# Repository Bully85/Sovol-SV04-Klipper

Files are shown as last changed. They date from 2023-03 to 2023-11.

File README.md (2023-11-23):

Pleas use the newest release for download "[Release](https://github.com/Bully85/Sovol-SV04-Klipper/releases)"

# Sovol-SV04-Klipper
This repository contains all the necessary configuration files for the SV04 to work with Klipper's Mirror and Copy modes, including images and descriptions.

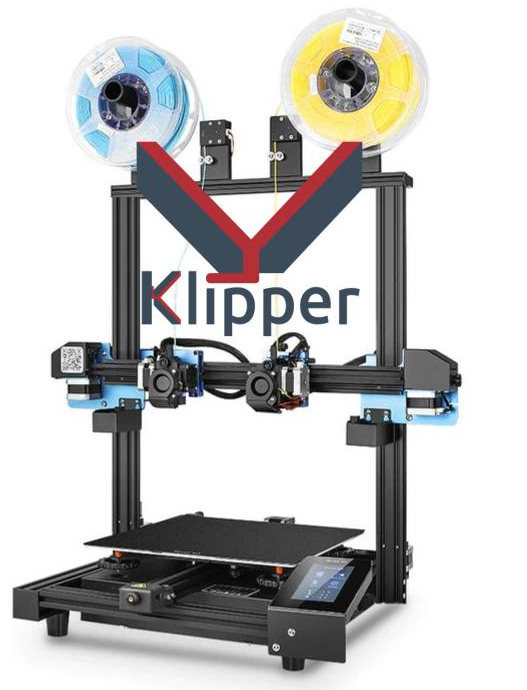
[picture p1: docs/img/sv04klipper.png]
KlipperSV04


# Spenden/Donations

Donate with PayPal (https://www.paypal.com/donate/?hosted_button_id=L85ULXXQKALP6)

# _Für die deutsche Anleitung wählt bitte READMEdeutsch.md_

# new
Click here for the Discord https://discord.gg/22VQXyuq
# update
Attention, the configs have changed with the new update. Please re-insert IDEX_mode.cfg, macros.cfg and Start-End-Macro.cfg. If the display is needed, these are in the config/SV04-with-display folder. Otherwise, if the original klipper is installed, config/SV04-works-with-orign-klipper can also be used but without the orign display

Change the Startcode in the Slicer [Cura](Cura Profile/Startcode.md) [Prusa_Slicer](Prusaslicer Profile/Startcode.md)
# Introduction

Different configs are required for the STM and GD versions of the printer.
Both are included in the "printer.cfg" file and you just need to uncomment the correct one.
You can verify whether your chip is STM or GD by either opening your electric box and checking manually, or there is an error message with the z-Tilt.

This guide will help you set up your SV04 with Klipper, including the COPY and MIRROR modes.

# In Progress

Cura 5.3 is currently not supported, but we are working on it.

# Features

- Copy Mode (supports different temperatures but does not support first layer settings for the right Extruder)
- Mirror Mode (supports different temperatures but does not support first layer settings for the right Extruder)
- Dual Mode
- Single Mode
- Bed Mesh Levelling
- Input Shaping
- Display Functionality
- And much more

# Requirements

- Raspberry Pi 3 or newer with WiFi
    - Pi Zero won't work 
    - Pi 2 may or may not work, not recommended
- Optional but recommended: Original 7" touch screen
- Optional: Camera
- SSH; For example:
    - Powershell and Windows Terminal have SSH built-in
    - alternatively Putty or another SSH program (https://putty.org/)
- SFTP or SCP; For example:
    - FileZilla (https://filezilla-project.org/)
    - WinScp (https://winscp.net)
- Pi Imager (https://www.raspberrypi.com/software/)
- The configuration files provided in this repository
- MicroSD Card for the Raspi (min 8GB, the complete install is ~5.5GB)
- SD Card to flash the SV04 (max 8GB, formatted in Fat32 4096)

# Installation via pre-made OS image

The operating system for the Raspberry Pi can be found in the "[image Raspberry PI 3_4](https://drive.google.com/drive/folders/1rZepxzwUR5QTXRXcv5EBYin_gFiMcKVD)" directory. 
This should be installed onto the MicroSD card using the [Raspberry Pi Imager](https://www.raspberrypi.com/software/). 
Make sure to adjust your WiFi settings before writing the image (you can find them by clicking on the cog wheel in the bottom right corner). 

The firmware.bin file in the "Firmware bin" directory should be placed on the (Full Size)SD card and flashed onto the printer with the original display unplugged (the original display is not needed at this stage as it will not function). 
The files from the "config" directory should now be transferred to the Raspberry Pi as described [below](#transferring-files), or directly in the Mainsail interface, which can be accessed by using the IP address or Hostname.
- the Hostname can be configured in the WiFi Settings in Pi Imager 
- the IP can be found in your router

# Installation on an Existing OS

## Without Kiauh

Coming soon.

## If you use Kiauh
Follow the [Kiauh](https://github.com/th33xitus/kiauh) instructions first, then come back.

- Log in to the Raspberry Pi [via SSH](#using-ssh) and enter the following command:
```sh 
sudo nano kiauh/klipper_repos.txt.example
```

- Add the following line at the end (see image below):
```sh 
https://github.com/Bully85/klipper
```
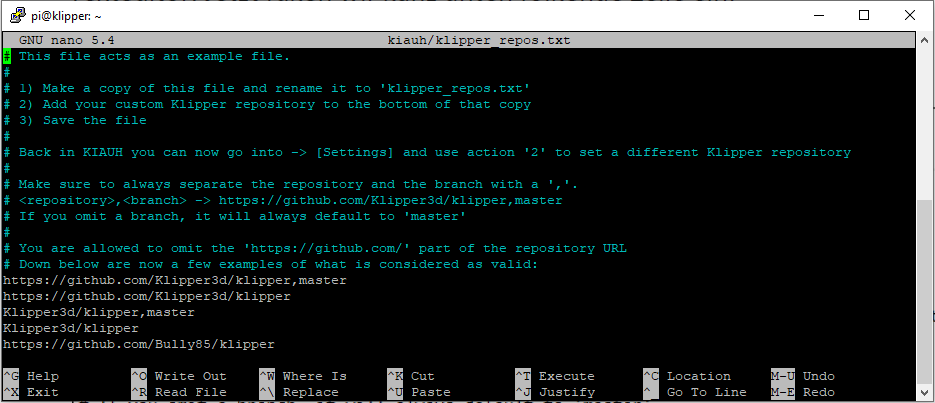
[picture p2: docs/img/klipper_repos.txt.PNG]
KiauhSV04


- Save the file with Ctrl+X -> Y. 
- Rename the file to remove ".example" from the file name and press Enter, then Y. 
- Run Kiauh with the command 
```sh 
./kiauh/kiauh.sh
```
- Select Settings [6] 
- Then [1] to set the custom Klipper repository
- Choose [4] "Bully85/klipper"
- Then confirm everything with [y].

Exit SSH

# Installation on a new OS 

Using the Raspi Imager, install Mainsail OS from 'Other specific-purpose OS' -> '3D printing' -> 'Mainsail OS'.
Then boot your Raspi, connect via SSH, and install [Kiauh](https://github.com/th33xitus/kiauh). 
Now follow the [instructions above](#if-you-use-kiauh) to overwrite the default Klipper install with this one.
Once done connect via SFTP/SCP, and transfer all the files from this repo's 'config' folder into 'printer_data/config/'.
Reboot the Raspi for good measure, and you're done.

# Using SSH

You can use SSH via a graphical interface as mentioned [above](#requirements), or via the Terminal.
If you choose something like putty, follow their instructions.
The Terminal is already installed and usually quicker.
- open the Windows Terminal (it's called Terminal, not the old CMD), or Powershell 
- connect by typing 'ssh username@hostname' and enter your password when prompted
    - username and hostname are the ones you set up [earlier](#installation-via-pre-made-os-image)
    - if you're installing onto an existing OS, I trust that you know the username and hostname/IP
- do what you need...
- to exit, press Ctrl+D

# Transferring Files 

Now, the files and folders from the "config" directory must be copied to your printer's directory on the Raspberry Pi. The default is "printer_data". 
If this is not the case for you, please adjust the paths in the config and .sh files. 

The easiest way to do this is via an SFTP or SCP Program, such as FileZilla or WinScp [mentioned above](#requirements)

# Fixing the Invalid Message in Mainsail

To fix the invalid message in Mainsail, SSH into Klipper and execute the following command:

```sh 
sudo nano ~/printer_data/systemd/moonraker.env
```
moonraker.env1

Append "-g"  to the end of the "MOONRAKER_ARGS" Line: 
moonraker.env2

Quit and save, then reboot. 

In Mainsail, click on 'invalid' and perform a soft repair. Your setup should now be ready!

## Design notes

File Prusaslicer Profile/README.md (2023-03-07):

# Install Profile PrusaSlicer

## Copy and import

- First copy the folder "SV04" in the Folder path:

```sh
C:\Program Files\Prusa3D\PrusaSlicer\resources\profiles
```

- than import the "PrusaSlicer_config_bundle_SV04_Klipper.ini" in PrusaSlicer

## Use

- if you print in dual mode and dont use the other extruder select "NONE" Filament for the not used Extruder

- for the connection with klipper go to printer settings an clic the cog wheel.

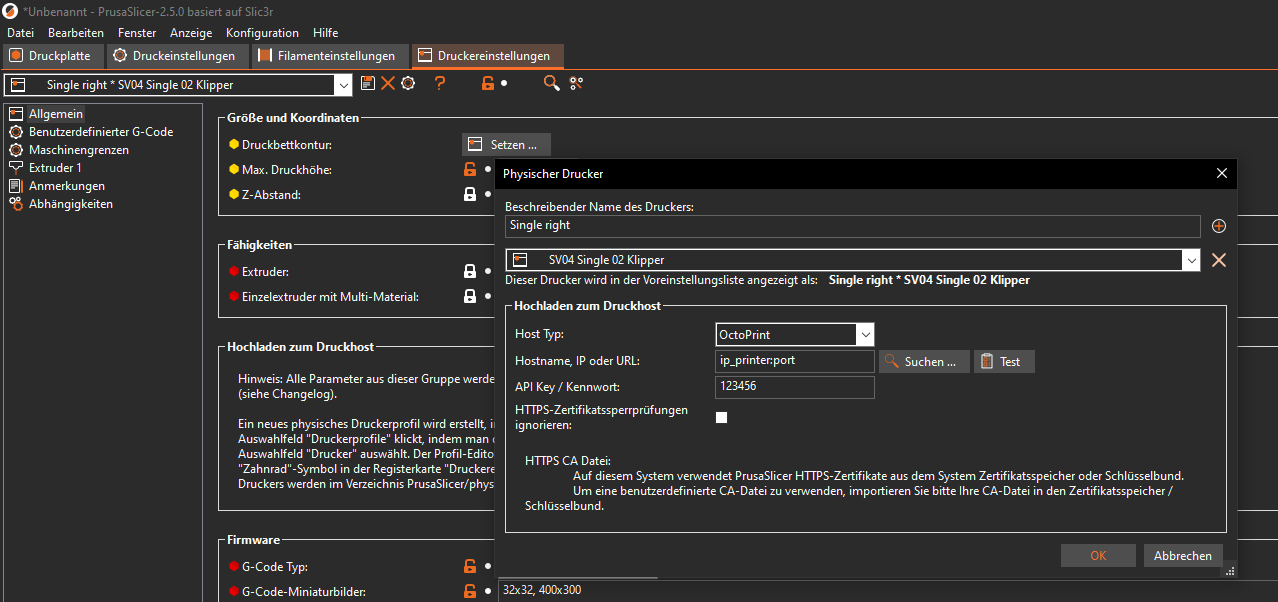
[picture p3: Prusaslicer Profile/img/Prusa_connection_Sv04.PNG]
PrusaSV04


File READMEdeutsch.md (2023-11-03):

# Sovol-SV04-Klipper
Dieses Repository enthält alle notwendigen Konfigurationsdateien, damit der SV04 mit den Spiegel- und Kopiermodi von Klipper funktioniert, einschließlich Bilder und Beschreibungen.

KlipperSV04

# Spenden

Donate with PayPal (https://www.paypal.com/donate/?hosted_button_id=L85ULXXQKALP6)

# Einleitung

Als erstes solltet Ihr überprüfen, welchen Chip Ihr habt. Entweder Ihr öffnet den Elekronikkasten und schaut was auf eurem Chip steht oder es kommt eine Fehlermeldung beim z-Tilt.

Diese Anleitung beschreibt, wie ihr euren SV04, inklusive der COPY und MIRROR modi, Klippern könnt.

# update
Achtung, die configs haben sich mit dem neuen Update geändert. Bitte fügen Sie IDEX_mode.cfg, Macros.cfg und Start-End-Macro.cfg erneut ein. Wenn das Display benötigt wird, befinden sich diese im Ordner config/SV04-with-display. Andernfalls kann bei installiertem Original-Klipper auch config/SV04-works-with-orign-klipper verwendet werden, jedoch ohne das original Display

Wechsel des Startcode im Slicer [Cura](Cura Profile/Startcode.md) [Prusa_Slicer](Prusaslicer Profile/Startcode.md)

solltet ihr neu installieren befolgt weiter diese Anleitung
# In Arbeit..
Momentan wird Cura 5.3 nicht untersützt ! wir arbeiten aber dran... 

# Was geht alles?!!!

- Copy-Modus (unterstützt verschiedene Temperaturen, aber nicht die firstlayer Einstellungen für den rechten Extruder)
- Mirror-Modus (unterstützt verschiedene Temperaturen, aber nicht die firstlayer Einstellungen für den rechten Extruder)
- Dual Mode
- Single Mode
- Bed Mesh Levelling
- Input Shaper
- Das Display geht
- uvm.

# Benötigt
- Raspberry Pi mit W-Lan
- Optional aber empfohlen: Original 7“ Touchscreen
- Optional: Kamera
- SSH; Zum Beispiel:
    - Powershell und Windows Terminal haben SSH integriert
    - alternativ Putty oder ein anderes SSH-Programm (https://putty.org/)
- SFTP oder SCP; Zum Beispiel:
    - FileZilla (https://filezilla-project.org/)
    - WinScp (https://winscp.net)
- Pi Imager (https://www.raspberrypi.com/software/)
- Die von mir erstellten Config Dateien
- MicroSD-Karte für den Raspi (mindestens 8GB, die komplette Installation beträgt etwa 5,5GB)
- SD-Karte zum Flashen des SV04 (maximal 8GB, formatiert in Fat32 4096)

# Installation

Das Betriebssystem für den Raspberry findet ihr im Verzeichniss "[image Raspberry PI 3_4](https://drive.google.com/drive/folders/1rZepxzwUR5QTXRXcv5EBYin_gFiMcKVD)". 
Dieses wird mit Hilfe des [Raspberry Pi Imagers](https://www.raspberrypi.com/software/) auf die MicroSD-Karte gespielt. 
Achtet darauf gleich eure Wifi-Einstellungen anzupassen (diese findet ihr wenn ihr unten rechts auf das Zahnrad klickt). 

Die firmware.bin im Verzeichnis "Firmware bin" kommt auf die (große)SD-Karte und wird mit ausgestecktem original Display (wird vorerst nicht mehr benötigt, da es nicht mehr funktioniert) auf den Drucker geflasht. 
Die Dateien aus dem "config" verzeichniss werden dann, [wie unten beschrieben](#dateiübertragung) oder direkt im Mainsail Interface, auf den Raspberry übertragen. Sobald der Pi gestartet ist, kann das Interface per IP oder Hostname erreicht werden.

# Installation auf einem bestehendem OS

# Ohne Kiauh

beschreibung folgt .....

# Solltet ihr Kiauh nutzen
Folgt zuerst den [Kiauh](https://github.com/th33xitus/kiauh) Anweisungen und kommt dann zurück.

- Meldet euch per ssh beim Raspi an und gebt folgenden befehl ein:
```sh
sudo nano kiauh/klipper_repos.txt.example
```

- Dort fügt ihr am Ende der Datei die folgende Zeile ein (siehe Bild):
```sh
https://github.com/Bully85/klipper
```
KiauhSV04

- Speichert die Datei mit Ctrl+X -> Y
- Löscht das '.example' vom Ende des Dateinamens
- und öffnet Kiauh mit dem Befehl
```sh
./kiauh/kiauh.sh
```
- Hier wählen wir [6] Settings
- Dann [1] Set custom Klipper repository
- Dann [4] Bully85/klipper
- Und alles mit [ y ] bestätigen.

Fertig mit SSH

# Installation auf einem neuen OS

Installiert mit dem Raspi Imager das Mainsail OS aus 'Other specific-purpose OS' -> '3D printing' -> 'Mainsail OS'.
Startet dann euren Raspi, verbindet euch über SSH und installiert [Kiauh](https://github.com/th33xitus/kiauh).
Folgt den [vorherigen Schritten](#solltet-ihr-kiauh-nutzen), um die Standard-Klipper-Installation durch diese zu ersetzen.
Sobald ihr fertig seid, verbindet euch über SFTP/SCP und übertragt alle Dateien aus dem 'config'-Ordner dieses Repos in 'printer_data/config/'.
Startet den Raspi zur Sicherheit neu, und ihr seid fertig.

# Benutzung von SSH 

Ihr könnt SSH über eine [grafische Oberfläche](#benötigt) verwenden, oder über das Terminal.
Wenn ihr Putty benutzt, folgt deren Anweisungen.
Das Terminal ist schon installiert und normalerweise schneller.

- öffnet das Windows-Terminal (es heißt Terminal, nicht das alte CMD) oder Powershell
- verbindet euch mit 'ssh benutzername@hostname' und gebt Passwort ein
    - Benutzername und Hostname sind die, die ihr [oben](#installation-auf-einem-bestehenden-os) eingerichtet habt
    - wenn ihr auf ein bestehendes OS installiert, kennt ihr euren Benutzer- und Hostnamen hoffentlich schon/noch
- macht zeugs...
- zum Beenden Ctrl+D drücken

# Dateiübertragung 

Nun müssen die Dateien und Ordner aus dem "config"-Verzeichnis auf den Raspberry Pi kopiert werden. Standardmäßig in "printer_data".
Sollte dies bei euch nicht der Fall, passt bitte die Pfade in den Config- und .sh-Dateien an.

Am einfachsten geht das über ein SFTP- oder SCP-Programm, wie z.B. [FileZilla oder WinScp](#benötigt)

# Behebung der 'ungültig' Anzeige in Mainsail

meldet euch per SSH bei Klipper an und führt den folgenden Befehl aus:
```sh
sudo nano ~/printer_data/systemd/moonraker.env
```
moonraker.env1

Fügt "-g" am Ende der "MOONRAKER_ARGS"-Zeile an:
moonraker.env2

Speichern und Datei schließen.
Dann ein Neustart

In Mainsail klickt auf 'ungültig' und führt eine Soft Repair durch. 

fertig!!!!!

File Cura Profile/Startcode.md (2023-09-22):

# Mirror

M190 S0
M109 S0
G28 X
SET_DUAL_CARRIAGE CARRIAGE=1 MODE=MIRROR
START_PRINT EXTRUDER={adhesion_extruder_nr} EXTRUDERS=2 EXTRUDER_TEMP={material_print_temperature_layer_0, 0} EXTRUDER1_TEMP={material_print_temperature_layer_0, 1} BED_TEMP={material_bed_temperature_layer_0} AREA_START=%MINX%,%MINY% AREA_END=%MAXX%,%MAXY%

# Dual

M190 S0
M109 S0
G28 X
SET_DUAL_CARRIAGE CARRIAGE=0 MODE=PRIMARY
START_PRINT EXTRUDER={adhesion_extruder_nr} EXTRUDERS=2 EXTRUDER_TEMP={material_print_temperature_layer_0, 0} EXTRUDER1_TEMP={material_print_temperature_layer_0, 1} BED_TEMP={material_bed_temperature_layer_0} AREA_START=%MINX%,%MINY% AREA_END=%MAXX%,%MAXY%

# Copy

M190 S0
M109 S0
G28 X
SET_DUAL_CARRIAGE CARRIAGE=1 MODE=COPY
START_PRINT EXTRUDER={adhesion_extruder_nr} EXTRUDERS=2 EXTRUDER_TEMP={material_print_temperature_layer_0, 0} EXTRUDER1_TEMP={material_print_temperature_layer_0, 1} BED_TEMP={material_bed_temperature_layer_0} AREA_START=%MINX%,%MINY% AREA_END=%MAXX%,%MAXY%

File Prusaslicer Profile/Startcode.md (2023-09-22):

# Mirror

M190 S0
M109 S0
G28 X
SET_DUAL_CARRIAGE CARRIAGE=1 MODE=MIRROR
START_PRINT EXTRUDER=[current_extruder] EXTRUDERS=2 EXTRUDER_TEMP={first_layer_temperature[0]} EXTRUDER1_TEMP={first_layer_temperature[1]} BED_TEMP={first_layer_bed_temperature[0]}

# Dual

M190 S0
M109 S0
G28 X
SET_DUAL_CARRIAGE CARRIAGE=0 MODE=PRIMARY
START_PRINT EXTRUDER=[current_extruder] EXTRUDERS=2 EXTRUDER_TEMP={first_layer_temperature[0]} EXTRUDER1_TEMP={first_layer_temperature[1]} BED_TEMP={first_layer_bed_temperature[0]}

# Copy

M190 S0
M109 S0
G28 X
SET_DUAL_CARRIAGE CARRIAGE=1 MODE=COPY
START_PRINT EXTRUDER=[current_extruder] EXTRUDERS=2 EXTRUDER_TEMP={first_layer_temperature[0]} EXTRUDER1_TEMP={first_layer_temperature[1]} BED_TEMP={first_layer_bed_temperature[0]}

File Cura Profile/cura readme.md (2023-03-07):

# Path for the Profiles

```sh
C:\Program Files\Ultimaker Cura 4.12.1\resources\definitions
```
```sh
C:\Program Files\Ultimaker Cura 4.12.1\resources\extruders
```
```sh
C:\Program Files\Ultimaker Cura 4.12.1\resources\meshes
```
## Path change version 5

```sh
C:\Program Files\Ultimaker Cura 5.1.0\share\cura\resources\definitions
```
```sh
C:\Program Files\Ultimaker Cura 5.1.0\share\cura\resources\extruders
```
```sh
C:\Program Files\Ultimaker Cura 5.1.0\share\cura\resources\meshes
```

## add Bed Mesh printarea

paste the file "MeshPrintSize.py" to the folder Script. Look photos

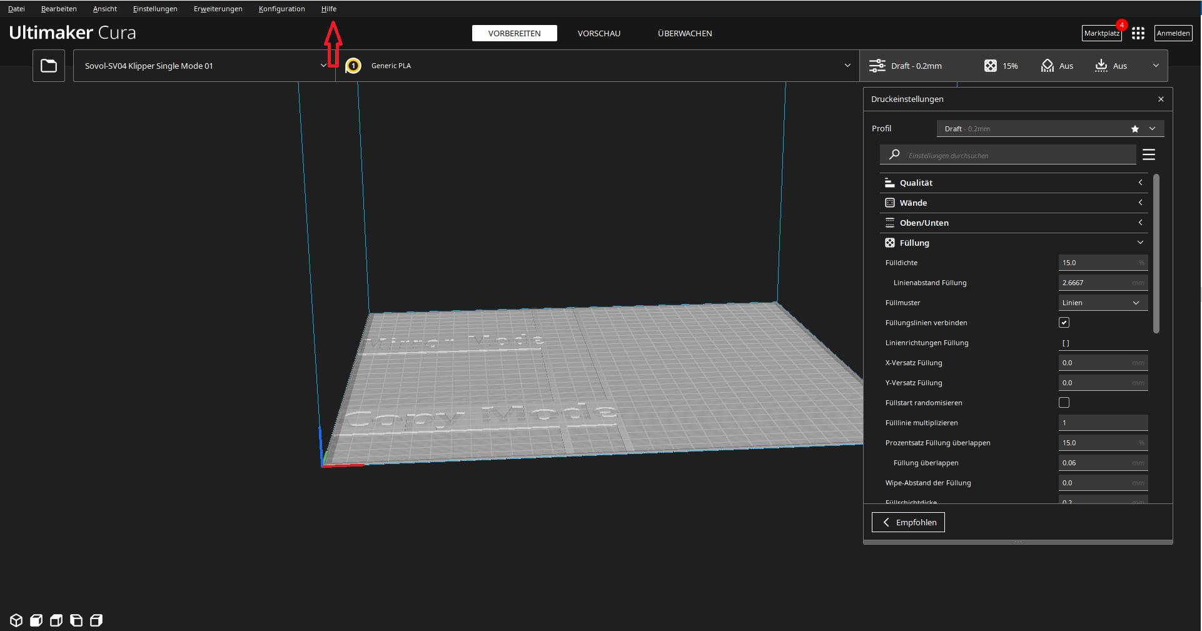
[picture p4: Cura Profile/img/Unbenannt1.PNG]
pic1SV04

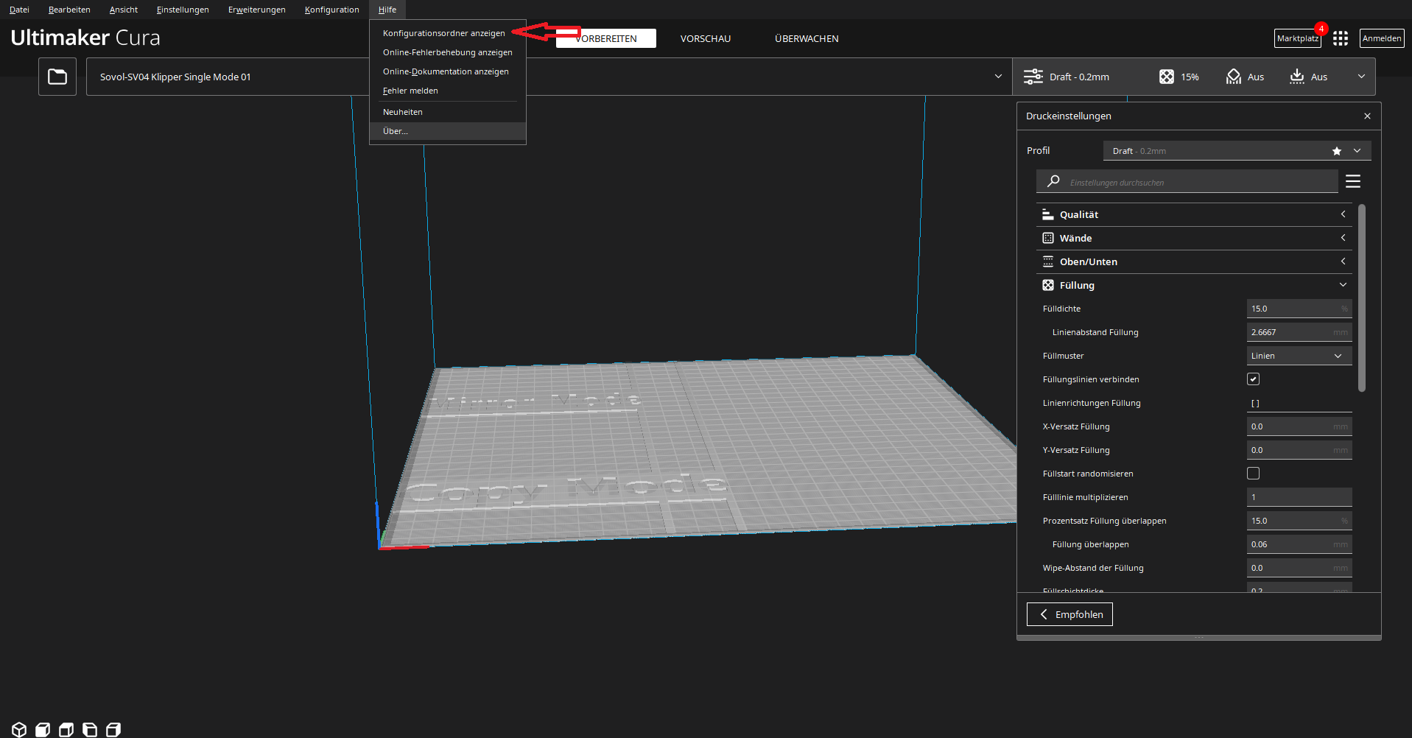
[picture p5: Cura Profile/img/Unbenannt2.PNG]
pic2SV04

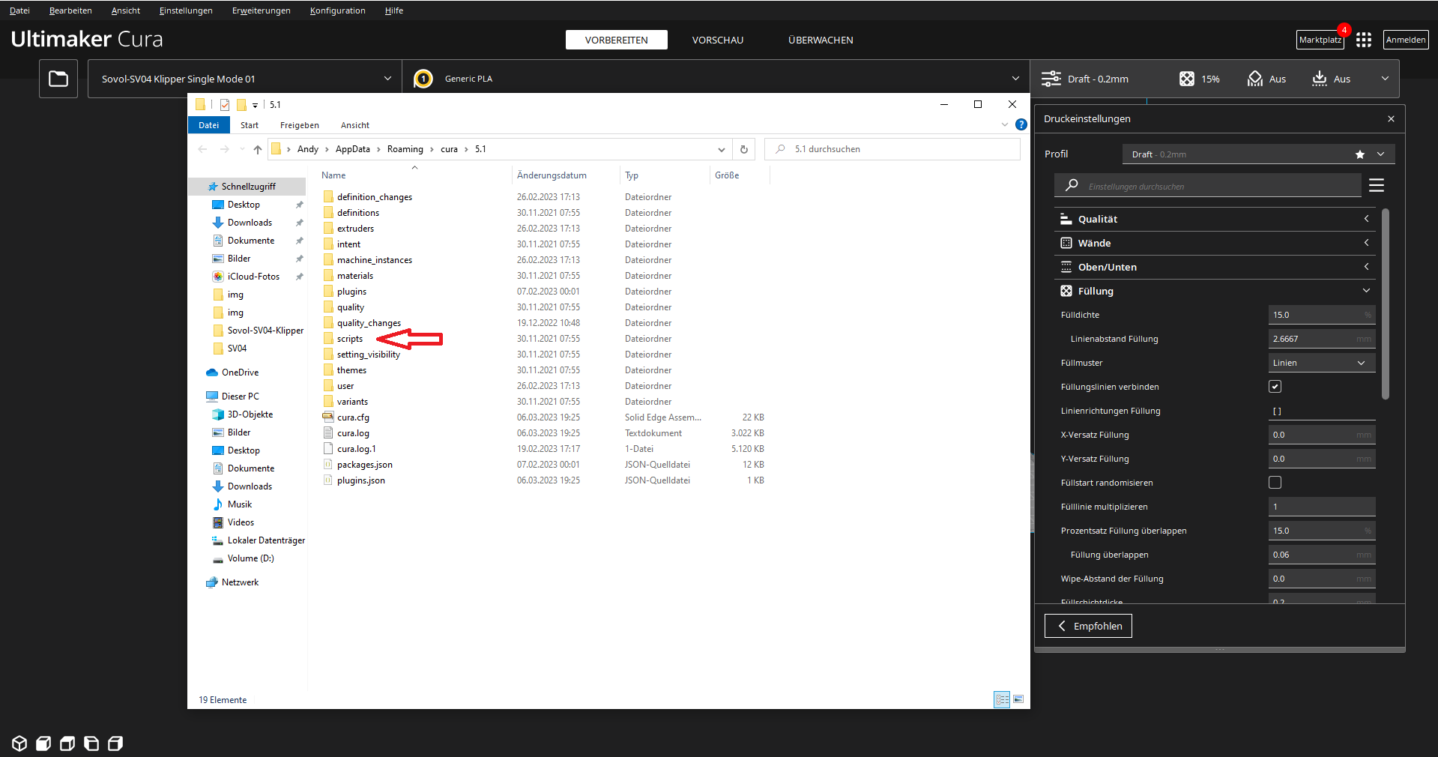
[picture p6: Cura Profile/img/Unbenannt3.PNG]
pic3SV04

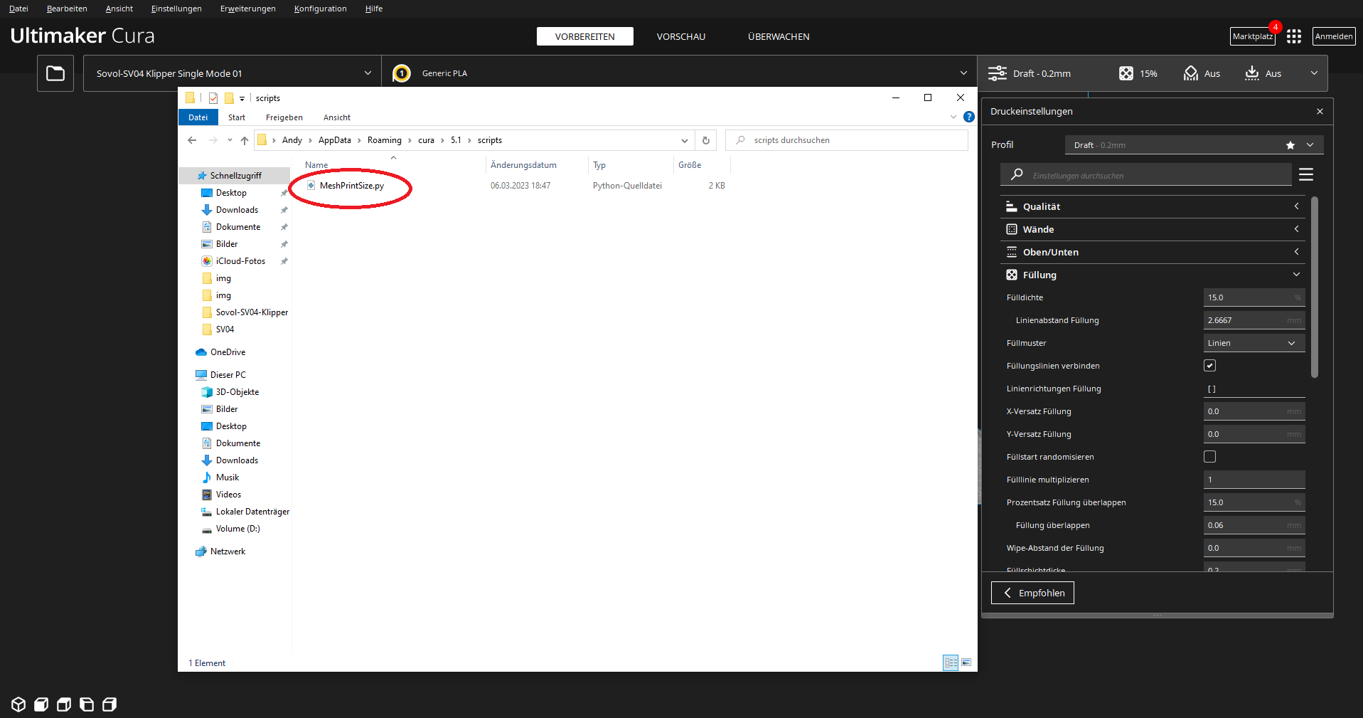
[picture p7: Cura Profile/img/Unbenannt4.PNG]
pic4SV04


- reboot Cura

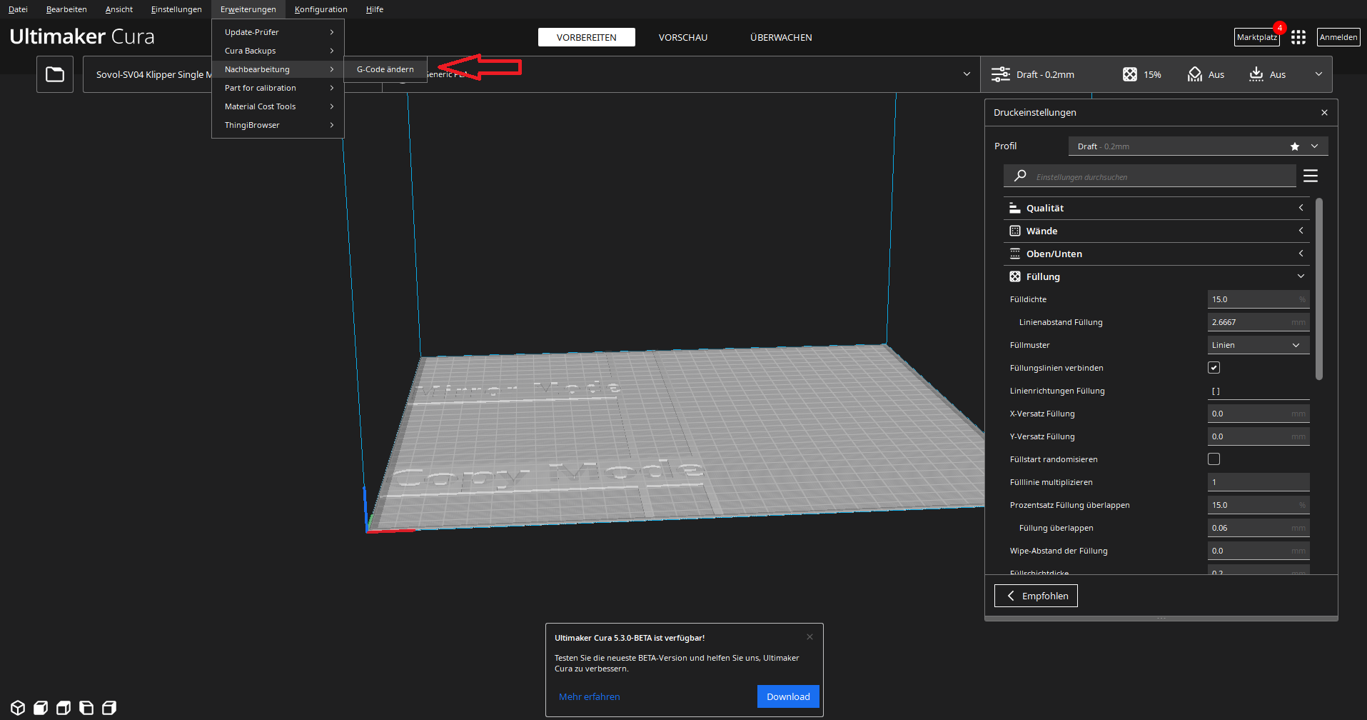
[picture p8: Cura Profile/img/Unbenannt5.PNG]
pic5SV04

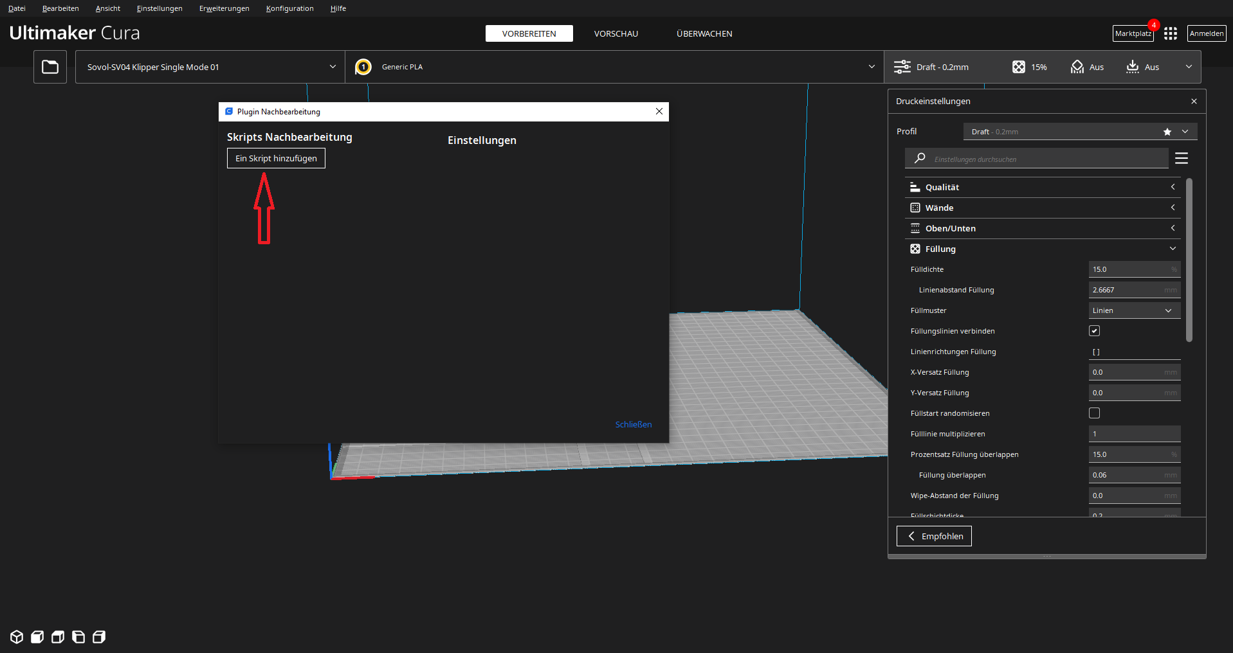
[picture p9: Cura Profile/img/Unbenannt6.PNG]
pic6SV04

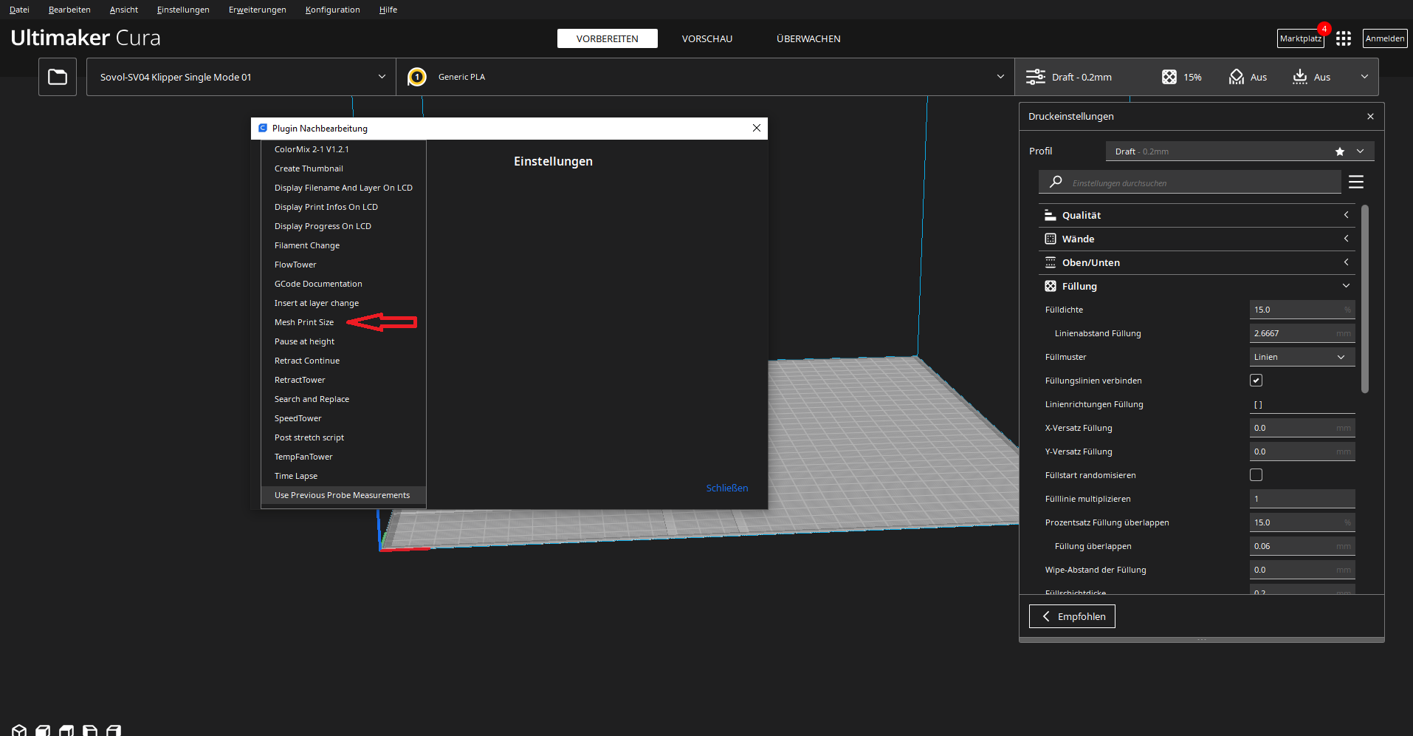
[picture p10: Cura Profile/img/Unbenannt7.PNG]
pic7SV04

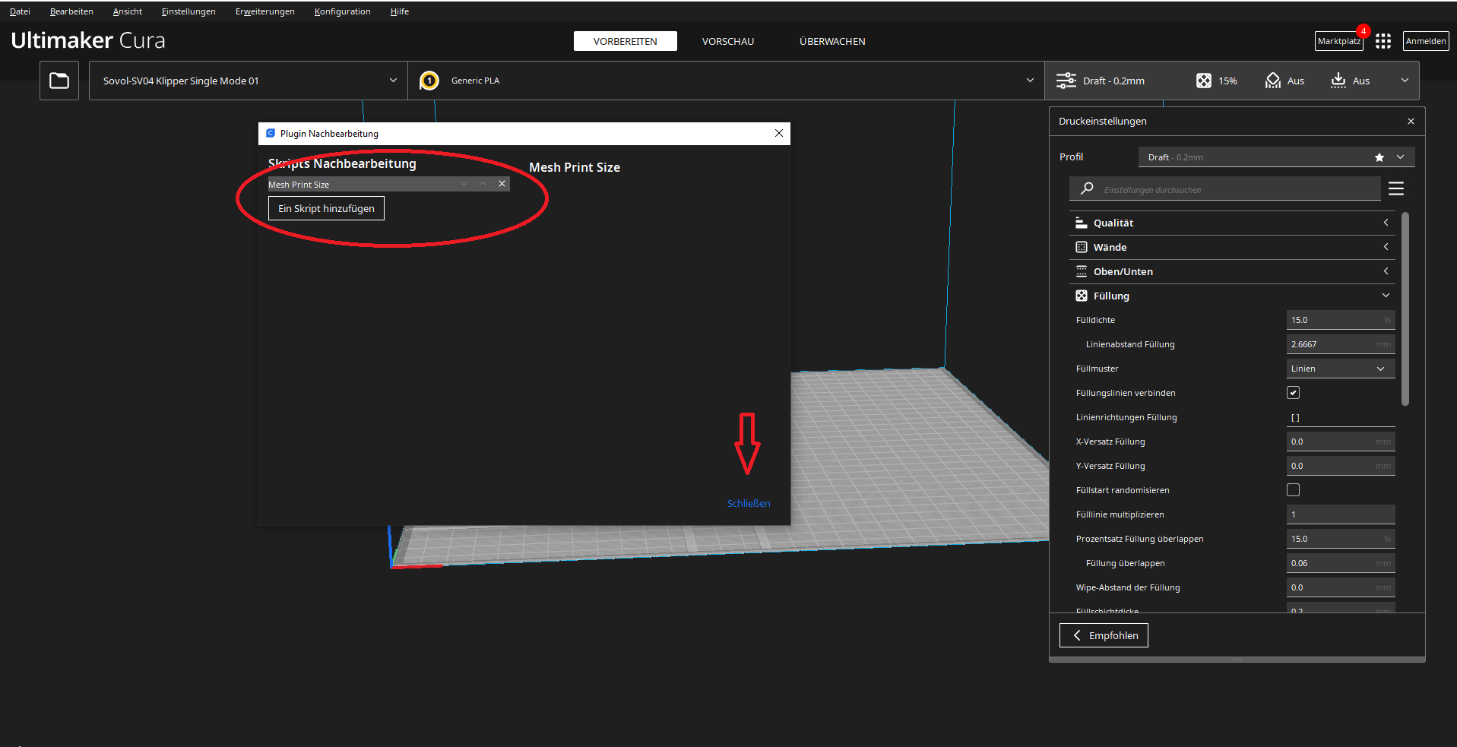
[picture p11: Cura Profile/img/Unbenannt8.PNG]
pic8SV04

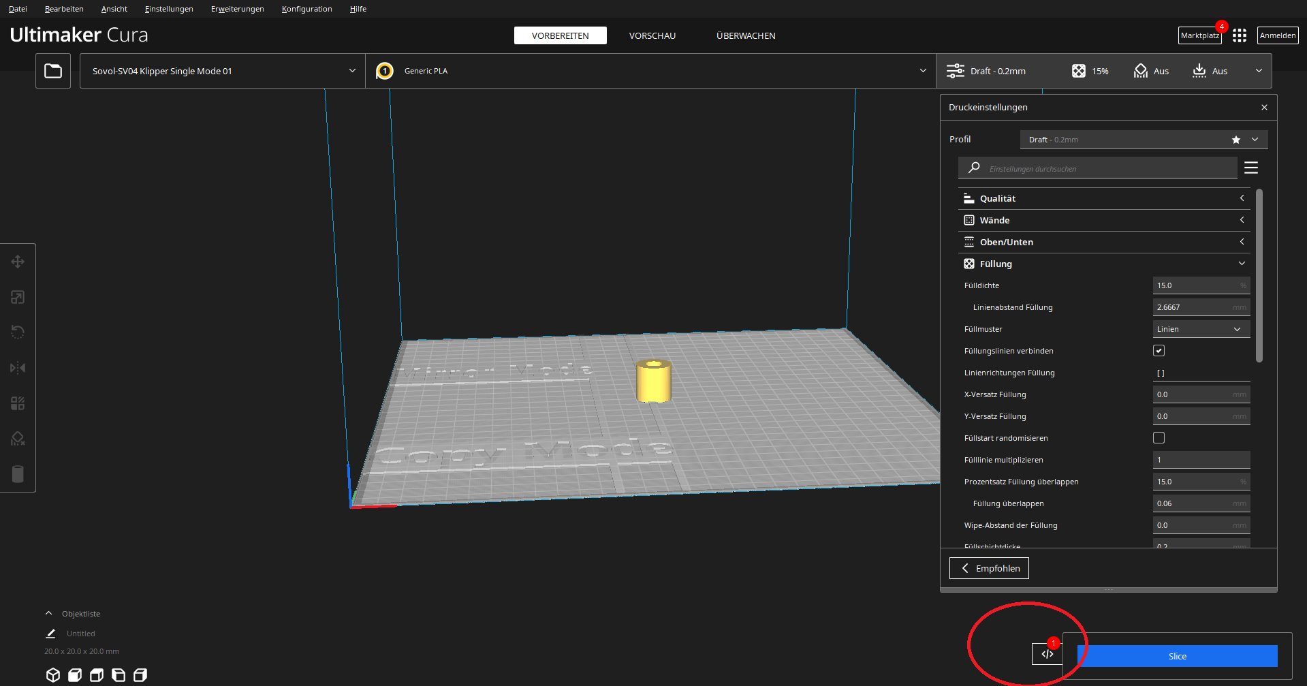
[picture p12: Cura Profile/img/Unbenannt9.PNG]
pic9SV04


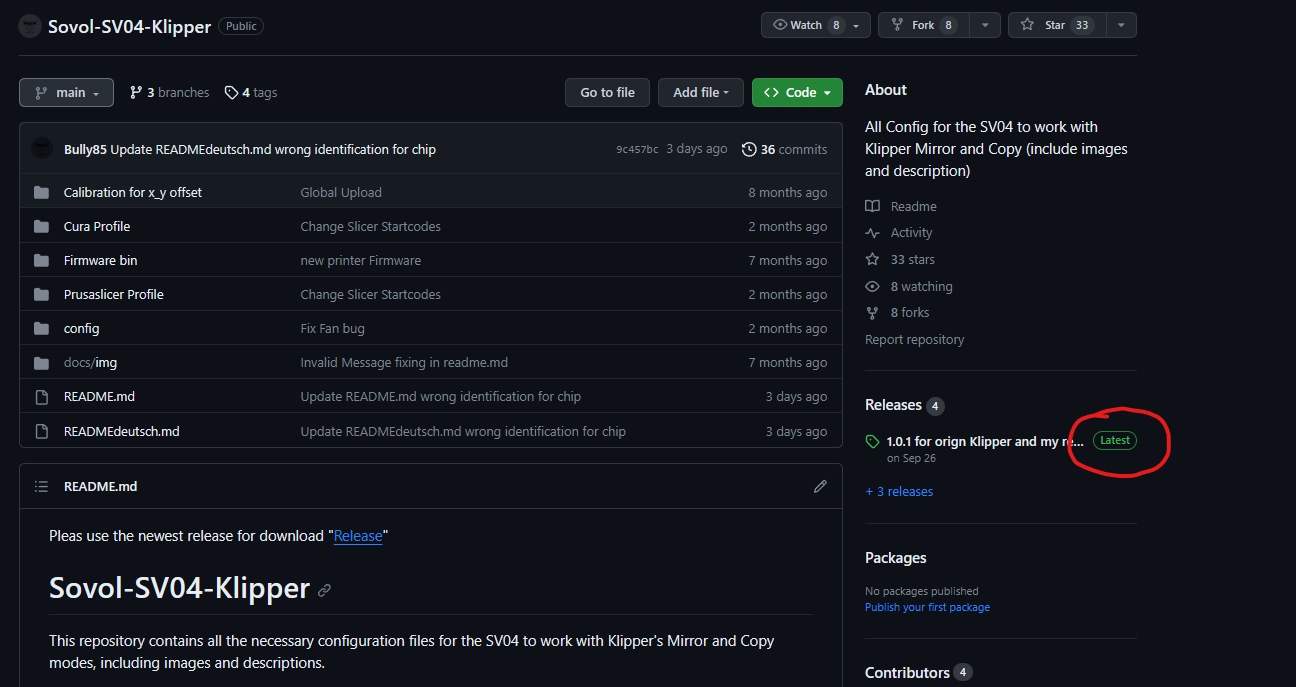
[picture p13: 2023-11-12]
docs/img/download1.png

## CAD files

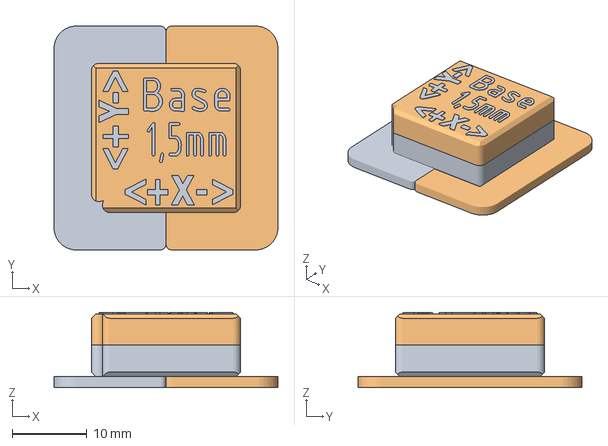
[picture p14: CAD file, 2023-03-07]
Calibration for x_y offset/IDEX-Cube-WK_V2.3mf
30.0 x 30.0 x 10.1 mm
IDEX-Cube-WK-T0.stl
IDEX-Cube-WK-T1.stl

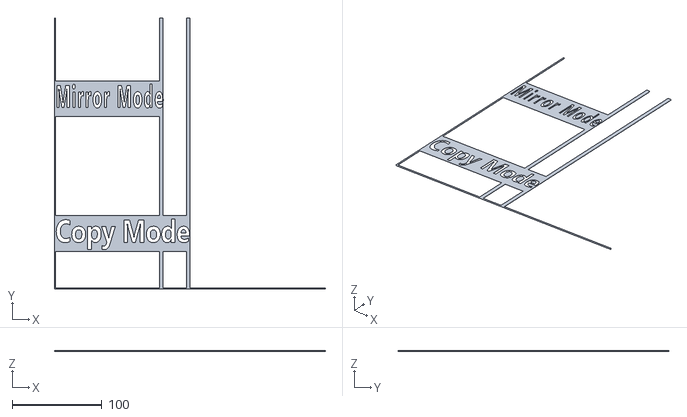
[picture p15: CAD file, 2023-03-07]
Cura Profile/meshes/SV04.STL
302.0 x 302.0 x 1.00

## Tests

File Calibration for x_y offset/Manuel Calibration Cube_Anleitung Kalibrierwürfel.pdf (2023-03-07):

Manuel Calibration Cube/ Anleitung Kalibrierwürfel

As requested here is the upload of my IDEX-CUBE.
Slicing instructions::
Change the group with the upper cube to the right extruder (T1) 1st layer heigth: 0,3mm
Base layer heigth: 0,2mm
Bottom layers: 2
Top layers: 2
Perimeters/Wall: 2
Infill: 20%
For further instructions please see the previously uploaded g-code of V1 of this part. I had to select the 3mf file type because when using stl there were too many parts. Be sure to know how to handle a caliper gauge correct.
Using my usual setting the cube prints in 21 minutes.
Example
Picture1 show: 25,7mm Picture2: 20mm Now

25,70-20=5,7

5,7 left also + = +5,7 X Axis

Wie gewünscht hier der Upload meines IDEX-CUBE. Schnittanleitung::
Gruppe mit dem oberen Würfel auf den rechten Extruder ändern (T1)
1. Schicht Höhe: 0,3mm
Grundschichthöhe: 0,2mm
Untere Schichten: 2
Obere Schichten: 2
Konturen/Wände: 2
Füllung/Fülldichte: 20%
Weitere Anweisungen finden Sie im zuvor hochgeladenen g-Code von V1 dieses Teils. Ich musste den 3mf Dateityp auswählen, weil es bei stl zu viele Teile gab. Vergewissern Sie sich, wie man mit einem Messschieber richtig umgeht.
Ich benutze meine übliche Einstellung der Würfeldrucke in 21 Minuten.
Beispiel
Bild1 zeigt: 25,7mm Bild2: 20mm Also jetzt

25,70-20=5,7

5,7 nach links also + = +5,7 X Achse

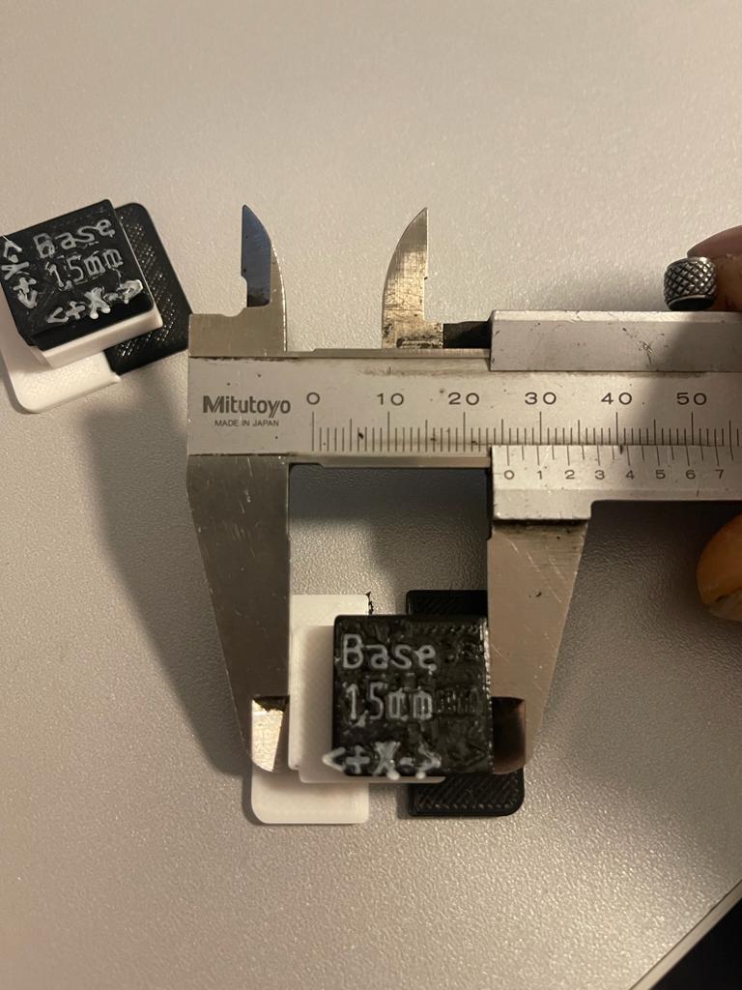
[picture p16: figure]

Bild 1/ Picture 1

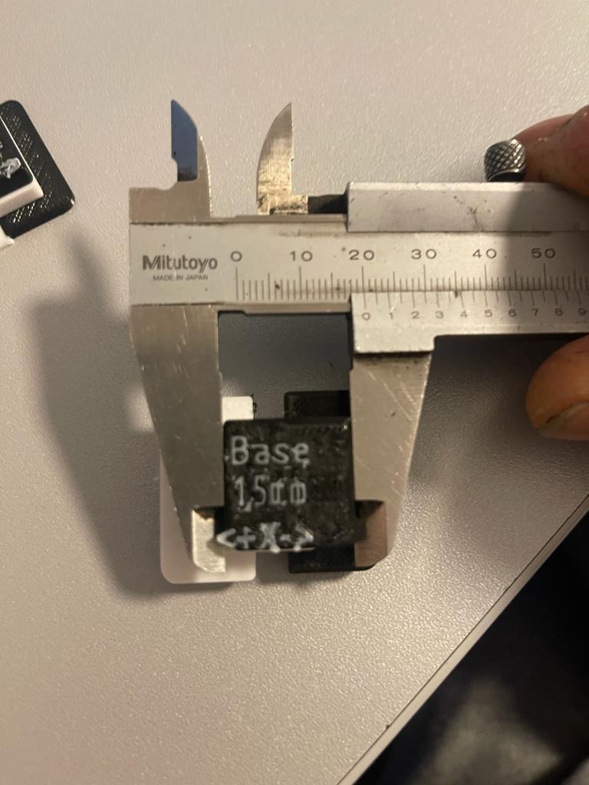
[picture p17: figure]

Bild 2/ Picture 2

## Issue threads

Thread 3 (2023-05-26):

Is this good to use with sonic pad?

scuba1976, 2023-05-26:
Is this good to use with sonic pad? Is it possible to use all sv04 function on sonic pad?

Bully85, 2023-05-26:
For use this you must choose my repo. At the moment sonic pad do not support to change the repo sorry

scuba1976, 2023-06-05:
Dear friend, i tried to do all the steps with raspberry 3b+. but i cannot connect to the printer. which firmware i have to use? there are two file.
I just need to copy all .cfg in config?
thanks

scuba1976, 2023-06-05:
Hello, i need you help. I install everything on my sv04. i have GD32F303, but z axis doesn't work. what i make mistake?
thanks

Bully85, 2023-06-05:
Do you change the z sector in printer.cfg

scuba1976, 2023-06-06:
Hello, i'm sorry to bore you. I success in all the steps and i start to print. The problem is that, after z tilt calibration with right extruder, it seams to start printing with left extruder. Can you help me? thanks

Funkelfetisch, 2023-10-09:
reopening this, anybody checked out:

https://github.com/smwoodward/Sonic-Pad-Updates/blob/main/root_access/Root

yet?

Closed 2023-06-12.

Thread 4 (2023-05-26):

Getting "Probe samples exceed samples_tolerance" error

IvajloFromHere, 2023-05-26:
Getting this error when using Prusa Slicer 2.5.2 with the configuration provided from this repo. Note that i get this error only from Prusa. The Cura works fine.

IvajloFromHere, 2023-05-27:
I solve my issue. I get this error because is select STM32 but my chip is Giga Device GD32.

Closed 2023-05-27.

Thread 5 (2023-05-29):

Reflash to marlin possible ?

pleasanthill17, 2023-05-29:
I am considering flashing to Klipper. However since this not special repo, I am wondering if you can return to Marlin - reflash to Marlin in the future after trying Klipper ? Thanks for your work on this !

Bully85, 2023-05-29:
Yes every time is possible. You only must flash the bin and dwin set for marlin

animerunt, 2023-07-06:
Is there anything special that needs to be done to flash the screen to another update?
I successfully flashed johncarlsons firmware over the klipper firmware.
I'm attempting to flash the screen with his screen firmware too:
https://github.com/johncarlson21/SV04-Touchscreen/releases

My SD card is good and formatted to fat32, same as when I flashed your screen firmware.
When I turn it on to update, it just goes to the klipper menu, which of course doesn't work now that the main firmware is back to marlin.

animerunt, 2023-08-18:
Sorry for the delay. I was able to flash the screen firmware after trying a different SD card.
I had been busy and only just got around to trying this again.
Thanks for your hard work! I will probably return in the future after it's updated more to try klipper again!

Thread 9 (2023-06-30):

STM or GD chip?

az1984, 2023-06-30:
In the guides, you state:

"Before starting, verify whether your chip is STM or GD. You can do this by either opening your electric box and checking manually, or by navigating to 'Machine -> System Loads -> mcu' in Mainsail."

But I don't understand what to do with that information. The README.md doesn't mention doing X if it's STM and Y if it's GTD. I also didn't see two distinct firmware files... Is the project only compatible with one or the other?

Can you please clarify?

Bully85, 2023-06-30:
You're right. It's a bit unmanageable. I'll review this over the weekend. The firmware is the same in both cases. Only in the Printer.cfg must the correct one be activated under z axis and the wrong one commented out or deleted.

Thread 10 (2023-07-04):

Retries aborting: Probed points range is increasing.

S1mone01, 2023-07-04:
I followed the entire installation for my Sovol sv04 but when I try to print any object and i get the following error:
Retries aborting: Probed points range is increasing.

Bully85, 2023-07-04:
Do you change the z part in Printer.cfg for gd chip?

S1mone01, 2023-07-04:
I just tried to change the settings from printer.cfg but now I get the error: BLTouch failed to deploy

Bully85, 2023-07-04:
Great

Closed 2023-07-06.

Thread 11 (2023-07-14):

Klipper issue with variables.cfg

CornBred89, 2023-07-14:
I get the following error when I launch mainsail for my SV04:

Internal error during connect: [Errno 2] No such file or directory: '/home/Klipper/printer_data/config/variables.cfg'

Once the underlying issue is corrected, use the "RESTART"
command to reload the config and restart the host software.
Printer is halted

How can I fix this? I have updated the printer.cfg file with all my corrected values from a previous Klipper install on my SV04.

Bully85, 2023-07-14:
The variables.cfg is missing

CornBred89, 2023-07-14:
I uploaded all of the configuration files, including the variables.cfg file, to mainsail before I got the error. I even tried including it in the printer.cfg file. That didn't work either.

CornBred89, 2023-07-15:
Nevermind, I figured it out. I have two instances of moonraker on my pi. So, I had to go into the misc.cfg file and update the file paths found in that config file.

Bully85, 2023-07-16:
Ok than you must rename the path

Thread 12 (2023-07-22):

Tool change issue in dual print mode

CornBred89, 2023-07-22:
Hello, I am having an issue where when the tool change is called, T1 wants to go to X-61 with T0. This is creating the following error, "Move out of range: -62.000 171.612 2.695 [0.000]."

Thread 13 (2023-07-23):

Cura 5.3

Malvus524, 2023-07-23:
Maybe it's a stupid question but in the description you mention Cura 5.3 is currently not working.
Does this mean any newer version is affected as well?
Because at the moment I am using Cura 5.4 and I don't know where I should get any older version.
I don't want to configure it all and can't use it at the end.

Thanks for your help and the overall effort to provide this config to the community up front

Bully85, 2023-07-23:
Sorry at the moment I must work very hard in my main job I try to test it tomorrow

Bully85, 2023-07-23:
But you can import the profile an slice a stl. Than Post the gcode head. The problem of 5.3 is that this don't give the extruder park to Klippe start macro

Malvus524, 2023-07-23:
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

Malvus524, 2023-07-23:
What is missing now?

Malvus524, 2023-07-23:
If you send me pictures from the correct start and end g code and I add it to the Cura start and end g code it should be fine

Bully85, 2023-07-23:
The problem is the same extruder parms only -1 must be 1 or 0

Bully85, 2023-07-23:
Cura change the extruder Parma's.with 5.3 I search for a way that allow 1 startcode for all slicer

Bully85, 2023-07-23:
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

Malvus524, 2023-07-23:
I don't quite get it yet.
Mainly I want to use dual mode because even if I use only one extruder I simply select extruder 1 or 2 in Cura.
Can you send me a picture from the whole start g code (not just the post/prefixes in Cura) I need to get dual mode working please?

Funkelfetisch, 2023-10-08:
any update on this?
I have a creality sonicpad here and want to hook it up :D

Bully85, 2023-10-08:
If the sonically up to date with the origin repo? Than it will be work with my new release. Not without the original display

Bully85, 2023-10-10:
Das problem ist, dass ich noch nicht herausgefunden habe wie ich ab cura 5.3 die variable setzen muss, dass er übermittelt mit welchem extruder er anfängt im Dual Modus. Ich werde diese Woche mal auf 5.4 updaten und mich damit beschäftigen

andrezanna, 2024-08-03:
Hello, I was able to correctly print with cura 5.8 by usign this little script to change the start extruder
```
import re
from ..Script import Script

class ChangeStartExtruder(Script):

    def getSettingDataString(self):
        return """{
            "name": "ChangeStartExtruder",
            "key": "ChangeStartExtruder",
            "metadata": {},
            "version": 2,
            "settings":{}
        }"""

    def execute(self, data):

        incremented_extruder_nr = None

        print(data)
        for layer_number, layer in enumerate(data):
            extruder_result = re.search("START_PRINT EXTRUDER=-?(\d+)", layer)
            print(extruder_result)
            if extruder_result:
                extre_string=extruder_result.group().split('=')[1]
                print(extre_string)
                extruder_nr = int(extre_string)
                print(extruder_nr)
                incremented_extruder_nr = extruder_nr + 1
                print(incremented_extruder_nr)
                data[layer_number] = re.sub("START_PRINT EXTRUDER=-?(\d+)", "START_PRINT EXTRUDER="+str(incremented_extruder_nr), layer)

        return data

```

Print went perfectly fine

Malvus524, 2024-08-06:
How did you install this script?

andrezanna, 2024-08-06:
Follow the same procedure for the printMeshSize script, Just enable ChangeStartExtruder

Malvus524, 2024-08-06:
okay i have tried but it looks like this:
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

That dosen't seem right

Malvus524, 2024-08-06:
it just says [current_extruder] no matter what extruder it should start with

andrezanna, 2024-08-06:
If you disable the script what value do you have there?

andrezanna, 2024-08-06:
And which klipper base profile do you use?

Malvus524, 2024-08-06:
its the same as with the script.

i don't get the question

andrezanna, 2024-08-06:
Strange, I was getting a different value.

I mean when you create a printer there are many sv04 klipper profile, which one did you use?

Malvus524, 2024-08-06:
I used the profile from this GitHub

andrezanna, 2024-08-06:
Ok, then can you try with this:

```
import re
from ..Script import Script

class ChangeStartExtruder(Script):

    def getSettingDataString(self):
        return """{
            "name": "ChangeStartExtruder",
            "key": "ChangeStartExtruder",
            "metadata": {},
            "version": 2,
            "settings":{}
        }"""

    def try_parse_int(s, base=10, val=None):
      try:
        return int(s, base)
      except ValueError:
        return val

    def execute(data):

        incremented_extruder_nr = None

        for layer_number, layer in enumerate(data):
            matchline = re.search("START_PRINT EXTRUDER([^\s]+)", layer)
            if matchline:
                elements=layer.split(" ");
                for chunk in elements:
                    extruder_result=re.search("EXTRUDER([^\s]+)",chunk)
                    if extruder_result:
                        extre_string=extruder_result.group().split('=')[1]
                        extruder_nr = try_parse_int(extre_string,val=-1)
                        incremented_extruder_nr = extruder_nr + 1
                        data[layer_number] = re.sub("START_PRINT EXTRUDER=([^\s]+)", "START_PRINT EXTRUDER="+str(incremented_extruder_nr), layer)
    
        return data

```

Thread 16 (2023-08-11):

trying to follow the instructions in readme.md, but config files unclear

Dweinbach, 2023-08-11:
Trying to install but no joy.

first i tried the image but always got 404 from NginX

then I tried my working (desktop OS) pi image, and got alot farther, but the readme.md says "copy the config folder to printer_data". is this really correct - like all the files in the repo's config folder go into /home/[mynamehere]/printer_data ? Not into /home/[mynamehere]/printer_data/config ? I need more clarity.

RizeCrime, 2023-08-11:
the entire config folder needs the be copied into printer_data.
So you want to end up with "xyz/printer_data/config/printer.cfg" (and all the other config files ofc).

It's clearer under "Installation on a new OS", the other section needs to be updated.

Dweinbach, 2023-08-12:
I would suggest changing:
"Now, the files and folders from the "config" directory must be copied to your printer's directory on the Raspberry Pi. The default is "printer_data". If this is not the case for you, please adjust the paths in the config and .sh files."
to:
"Now, the entire "config" folder and its contents must be copied to your printer's directory on the Raspberry Pi. The default is "~/printer_data". If this is not the case for you, please adjust the paths in the config and .sh files."

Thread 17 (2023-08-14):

Are these screw designations correct?...

Dweinbach, 2023-08-14:
in printer_.cfg:

[bed_screws] # BED_SCREWS_ADJUST
screw1: 25,35
screw1_name: front left screw

screw4:	295,35
screw**_2_**_name: front right screw

screw3: 295,295
screw3_name: back right screw

screw2: 25,295
screw**_4_**_name: back left screw

Bully85, 2023-08-23:
Hello I think yes. I can't check this because my printer is not original

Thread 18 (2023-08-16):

printer settings/general/gcode flavor=Marlin?

Dweinbach, 2023-08-16:
I'm not sure I loaded the PrusaSlicer template correctly, but it does print. I'm curious if the printer settings/general/gcode flavor should be marlin or klipper. it seems to be set to Marlin in my case, but I didn't know if this was intentional.

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

RizeCrime, 2023-08-16:
Yes, that is intentional.
Up until recently PrusaSlicer did not have a "Klipper" G-code flavor, so "Marlin" was the only option.
That said, since it does now have a "Klipper" flavor, it should work just the same, just try it out.

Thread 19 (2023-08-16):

Filament Unload in KlipperScreen is missing UNLOAD_FILAMENT Macro

Dweinbach, 2023-08-16:
I just tried to use unload filament in KlipperScreen, and it says "Macro UNLOAD_FILAMENT not found" for both extruders.

Bully85, 2023-08-23:
I check this

2greatsecret, 2024-05-22:
The problem is still present.
It is also not preheated when you want to load or unload filament

2greatsecret, 2024-05-22:
I copied the following macro from Kingroon KLP1 into macros.cfg and adjusted it very slightly (the filament length when loading and unloading).
Works quite well, even if not as well as the KLP1

```
[gcode_macro LOAD_FILAMENT]
gcode:
    M104 S220
    M105
    M109 S220
    G91
    G1 E50 F300
    G90

[gcode_macro UNLOAD_FILAMENT]
gcode:
    M104 S220
    M105
    M109 S220
    G91
    G1 E30 F3000
    G1 E-27 F9000
    M106 S255
    M104 S62
    M105
    M109 S62
    G1 E-100 F300
    M106 S0
    M84
```

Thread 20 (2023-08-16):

More of a question: Why does printer do a "mini" mesh probe when printing?

Dweinbach, 2023-08-16:
When printing from PrusaSlicer, the printer will do a "mini" mesh bed probe before every print. It looks like it is just of the actual area of the bed to be printed.

I assume this is intentional, but I don't see anything in the start g-code. is this just something Klipper does automatically?

ExaltedStudios, 2025-04-02:
Very delayed answer, but that's adaptive bed mesh in klipper.

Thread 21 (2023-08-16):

Suggestion: Add some post-install steps about configuring printer to readme

Dweinbach, 2023-08-16:
It would be helpful to add some steps for what needs to be done after successful install. Particularly Extruder1 x/y offset setting, but maybe there are others I don't know about? PID tune for example, which is already documented.

Bully85, 2023-08-23:
X/y only write in the macro. For other read the official Doku

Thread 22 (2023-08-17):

Should T0 and T1 Macros land on the same X coordinate?

Dweinbach, 2023-08-17:
Currently switching T0 to T0 or the reverse results in a difference in X position of the OFFSET_X value, I believe. It seems like the X value should remain the same before and after a toolchange.

This was observed when variable_offset_xin DC_VARS macro was hardcoded to the correct (negative) x offset, and dual_x_offset in variables.cfg = 0

Bully85, 2023-08-23:
Dc-vars not change use xy macro

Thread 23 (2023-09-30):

Original Display

Malvus524, 2023-09-30:
In the info you say something about an orig Display:
Do you mean the Original display from sovol or from the raspberry pi?
I ask because i cant get the Display from sovol to work.

Bully85, 2023-09-30:
Which firmware do you install?

Malvus524, 2023-10-01:
I was am using your old firmware but I have the configs updatet to the new ones but I can't get it to work.
I have updated start end macros, macros and index mode

Bully85, 2023-10-01:
You must use the new firmware.bin all you need is in release 1.0.1

Bully85, 2023-10-01:
https://github.com/Bully85/Sovol-SV04-Klipper/releases/tag/1.0.1

Malvus524, 2023-10-01:
it still does not work. i have installed your new firmware on the mcu but i cant get the display to change the bin into a cur.
what am i doing wrong?

Bully85, 2023-10-01:
Which config fiele you use?

Bully85, 2023-10-01:
Do you change the repository?

Malvus524, 2023-10-01:
The config file is the old one but I didn't change the repository

Malvus524, 2023-10-01:
Do I have to install the new firmware to both the display and the MCU?

Bully85, 2023-10-01:
for printer install: https://github.com/Bully85/Sovol-SV04-Klipper/releases/download/1.0.1/firmware.bin
for display: https://github.com/Bully85/DGUS-SV04/releases/download/1.0.0/DWIN_SET.rar

change the repository: https://github.com/Bully85/Sovol-SV04-Klipper#if-you-use-kiauh

the config: https://github.com/Bully85/Sovol-SV04-Klipper/releases/download/1.0.1/config.with.and.without.Display.rar

than import your slicer profiel cura(https://github.com/Bully85/Sovol-SV04-Klipper/releases/download/1.0.1/Cura.Profile.include.startcode_md.rar) or Prusa (https://github.com/Bully85/Sovol-SV04-Klipper/releases/download/1.0.1/Prusaslicer.Profile.include.startcode_md.rar)

now all must run

Malvus524, 2023-10-01:
Thank you very much

scuba1976, 2023-10-15:
I install original display and it works. It is normal the there isn't "print" command?

Bully85, 2023-10-15:
Yes at the moment. You can't start a print with the display. At the moment only for temp and cancel and secure stop

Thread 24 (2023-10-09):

Disqord invitation link not working

Funkelfetisch, 2023-10-09:
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

Bully85, 2023-10-10:
Ich kümmere mich drum

Bully85, 2023-10-12:
https://discord.gg/WfCyFjAzY 30 Days valid

jlsjonas, 2023-12-22:
Let's request again :)

Bully85, 2023-12-22:
In Wiki is the new link

jlsjonas, 2023-12-24:
Thanks for the response!
Where would that be? The 2 links I found are sadly enough marked as invalid by discord (https://github.com/search?q=repo%3ABully85%2FSovol-SV04-Klipper+discord&type=wikis, https://discord.gg/8Svd9usX & https://discord.gg/22VQXyuq)

Bully85, 2023-12-24:
https://discord.gg/xBbKEvxRNq

Bully85, 2023-12-24:
Ok now the link is permanently

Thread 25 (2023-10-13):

Unknown command:"SET_DUAL_CARRIAGE_MODE" and "Must home axis first: 0.000 0.000 0.200 [0.000]

scuba1976, 2023-10-13:
I updare klipper using this steps"https://github.com/Bully85/Sovol-SV04-Klipper#installation-on-an-existing-os"
Now, when i try to print in dual mode  it appears "Unknown command:"SET_DUAL_CARRIAGE_MODE" and "Must home axis first: 0.000 0.000 0.200 [0.000]" and the print don't start. can you help me?
[klippy.log](https://github.com/Bully85/Sovol-SV04-Klipper/files/12894522/klippy.log)

Bully85, 2023-10-13:
You don't have the correct config files use this https://github.com/Bully85/Sovol-SV04-Klipper/releases/tag/1.0.1

scuba1976, 2023-10-13:
I copied the file from config folder. I don't use original display. can you help me to put the correct config?

Bully85, 2023-10-13:
config/Sv04-works-with origin-klipper

You need Macro cfg idex cfg and start end macro cfg

scuba1976, 2023-10-13:
I copied all the config folder and file in printer data, but alwayes the same problem.
could be a problem with old
prusaslicer config?

Bully85, 2023-10-13:
Yes you must change it too

Bully85, 2023-10-13:
In the path is a text file with new start code

scuba1976, 2023-10-13:
Thanks, now it works. I get still two message : Hyperlaps unknown and dgus_print_start error. can you help me any more?

lucwuyts, 2023-10-23:
I think dgus_print_start is a command/macro to show something on the original display.
dgus_print_end is in macros.cfg
dgus_print_start and dgus_print_end is in  start_end_macro.cfg

I removed this because i use a PAD7 as display.  Original display is removed on my machine.

Bully85, 2023-10-23:
You're right

Bully85, 2023-10-23:
> Thanks, now it works. I get still two message : Hyperlaps unknown and dgus_print_start error. can you help me any more?

Can you take a screenshot

scuba1976, 2023-10-23:
I got everything. Thanks to all

Bully85, 2023-10-23:
Your welcome

Closed 2023-10-23.

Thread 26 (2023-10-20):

Must home axis first when resume after fillament runout

lucwuyts, 2023-10-20:
Fillament was runout , changed it, and pressed the resume button.
Now this message appears:
Must home axis first: 128.074 62.714 37.094 [142520.420]

Why is this?  The printer clearly knows where the head is.
And homing will collide with the unfinished print

Bully85, 2023-10-20:
Where do you press resume?

Bully85, 2023-10-20:
Can you try to reproduce it and make a video?

lucwuyts, 2023-10-20:
I press resume on the PAD 7 screen.
Will try to make a video.

lucwuyts, 2023-10-20:
First attempt: print continued as expected.   But this was now at the first layer.    I will try tomorrow with a simple tower at higher Z to repeat this.

Bully85, 2023-10-20:
Okay, I'm waiting for feedback

lucwuyts, 2023-10-21:
It seems after 2 hours, the bed and extruder heating stops, and when you press the resume button, this message appears.
Probably this is a bug in the PAD7  or Klipper itself?
I attach 2 photo's.  The first showing the printer is paused and extruder has cooled down, second after pressing the resume button.
In the 2 hours between the sensor detecting no more fillament, i was always able to restart the print.

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

lucwuyts, 2023-10-21:
I found an example to add to the printer.cfg file about controlling the idle_timeout.
But in this example, the temperature of the extruder is set to 0, the bed temperature is untouched.

When my printer has stopped with his current job, I will try this without the M104 code....

```
[idle_timeout]
gcode:
{% if printer.pause_resume.is_paused %}
M104 S0
{% else %}
TURN_OFF_HEATERS
M84
{% endif %}

```

Bully85, 2023-10-21:
M84 disable steper !!!!!!!

lucwuyts, 2023-10-21:
Yes, I don't care about the disable steppers instruction since the printer is possibly in a canceled state.
This addition solved the problem.  (I did erase the line with M104   S0)
I have been away for more than 4 hours, just returned, inserted the fillament again, and pushed resume.   Started as it should.

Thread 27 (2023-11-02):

Suggestion to add macros  LOAD_FILAMENT and UNLOAD_FILAMENT

lucwuyts, 2023-11-02:
I'm using the PAD7 on my SV04, and in the Extrude screen, there are 2 button's wich require the macros  LOAD_ and UNLOAD_FILAMENT

This is the screen (buttons LOAD and UNLOAD need this macros), the EXTRUDE buttons left and right are working

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

These are the macros I added to macros.cfg

```
# load and unload  macro
# printer is already in a paused state when this is called from the klipper - extruder screen on the PAD7
[gcode_macro LOAD_FILAMENT]
gcode:
 M83                   # Put the extruder into relative mode
 G92 E0.0              # Reset the extruder so that it thinks it is at position zero
 G1 E10 F350           # Move the extruder forward 10mm at a speed of 350mm/minute
 G92 E0.0              # Reset the extruder again
 M82                   # Put the extruder back into absolute mode.

[gcode_macro UNLOAD_FILAMENT]
gcode:
 M83                   # Put the extruder into relative mode
 G92 E0.0              # Reset the extruder so that it thinks it is at position zero
 G1 E-10 F350          # Move the extruder back 10mm at a speed of 350mm/minute
 G92 E0.0              # Reset the extruder again
 M82                   # Put the extruder back into absolute mode.
```

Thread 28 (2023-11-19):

Transfer macros and settings

RagDollino, 2023-11-19:
Hello, greetings from Argentina.

I have an idex printer with the same print dimensions running klipper, and I wanted to test your profile for idex modes, but I have the problem that when trying to start a print in copy or mirror mode, the "extruder 2" does not move in the x axis, It extrudes normally like 1... but it does not move in said axis, could you give me a clue on how to solve it? Thanks in advance

Bully85, 2023-11-19:
Can you give me more information what printer ist? Which board. How work the gantry

RagDollino, 2023-11-19:
I am with a tenlog D3P, with the stock 8-bit board, with an ATMEGA2560

Closed 2023-11-24.

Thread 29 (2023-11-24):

Problem with toolchange

RagDollino, 2023-11-24:
Doing a dual printing, when changing the tool, it raises 2mm as the macro says, but when the second extruder enters the first layer it prints in the air, then it lowers the 2mm for the next layer or when it has a travel without printing and it continues printing normally, at that moment if what it prints in the air is very large it ruins the entire piece, sorry by my english, its not my native language.

Bully85, 2023-11-30:
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

Can you try this

Closed 2024-01-09.

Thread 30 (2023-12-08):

[question] Why is a Raspi with 7" screen recommended

Basti-Fantasti, 2023-12-08:
Hi there,

I had a Raspi 3 with the official 7" display available and installed the Raspi image according to the documentation.
The printer has not been updated by now.

When I boot the raspi distro the 7" screen only shows the raspi login screen and remains in the terminal session.
So what adantage could I get out of this? I thought that maybe the WebUI is directly shown on the device itself.

Basti-Fantasti, 2023-12-08:
I've "installed" the raspi using your supplied img.
I flashed it directly to my micro sd card

Bully85, 2024-01-26:
Sorry I forget you. You must install Klipperscreen with kiauh

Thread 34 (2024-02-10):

z_tilt - corrected values

jokker87, 2024-02-10:
z_positions is supposed to be the virtual nozzel-position of the z-axis, in this case the stepper's rod position.

i also needed to switch the positions for z0 and z1, as it moved the wrong z-stepper to level the z tilt. maybe i'm just unlucky and the stepper got connected the other way around on the motherboard in the factory.

moving the points nearer to the center point speed up the process and resulted in more accurate z tilt leveling.

please let me know your opinion on the subject.

```
[z_tilt]
z_positions: 360,150
            -60,150
points: 102,150
        200,150
retries: 10
retry_tolerance: 0.02
speed:100
```

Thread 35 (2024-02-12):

Unable to connect printer

ginwer7619, 2024-02-12:
Hello, I followed the installation like descriptor but I am unable to connect the printer to Klipper. I always get the error mcu 'mcu': Unable to connect. I tried several cables, reinstalled several times everything but impossible to connect the printer.
I use a Raspberry Pi 4B with 7" TFT. On my Ender3 Neo there is no problem.
Where to find a solution for this connection problem.
Thank you

Bully85, 2024-02-12:
Do you install the mcu for pi?

https://www.klipper3d.org/Measuring_Resonances.html

https://www.klipper3d.org/RPi_microcontroller.html

ginwer7619, 2024-02-12:
Yes, I follow the install, no errors but unable to connect, always the mcu error and no serial device with. Always the message  ls: cannot access '/dev/serial/by-path/*': No such file or directory

Bully85, 2024-02-12:
After flash the firmware rename it from bin to cur?

ginwer7619, 2024-02-13:
Problem solved after isolating VCC pin on USB cable connection was made immediately.
Thanks

Bully85, 2024-02-13:
Thanks for feedback

Closed 2024-02-16.

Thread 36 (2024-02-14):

Kalibrierungswürfel

ginwer7619, 2024-02-14:
Hallo, ich habe den Kalibrierungswürfel gedruckt und eine Abweichung von 3,97mm. Nur finde ich nicht raus wo ich die +3,9 eingeben muss um die Abweichung zu korrigieren.
Sonst scheint alles zu funktionieren.
Vielen Dank für Ihre Hilfe.
Mit freundlichen Grüßen.

Bully85, 2024-02-14:
Es gibt das xy macro da gibst du es ein aber Achtung entweder x oder y sind + und - vertauscht einfach ausprobieren

ginwer7619, 2024-02-14:
Ist das im idex_mode.cfg unter
[gcode_macro DC_VARS]
# Offset coordinates for dual_carriage
variable_offset_x: 0
Gebe ich hier die abweichung ein. En xy macro habe ich nicht.

ginwer7619, 2024-02-15:
Hallo Habe das Problem gelöst, xy macro gefunden. Druck ist jetzt perfekt. Jedoch habe ich ein anderen Problem. Im copy mode läuft alles perfekt bis zum Druckbeginn, der Druck fängt an jedoch ohne aufheizen der Düsen und des Bettes.
Ich benutze Prusaslicer auf MAC, letzte version und das Prusaprofil  aus Sovol-SV04-Klipper-main. Vielen Dank im Voraus

ginwer7619, 2024-02-15:
Hallo, Ja steht drin
;TYPE:Custom
M190 S0
M109 S0
G28 X
SET_DUAL_CARRIAGE CARRIAGE=1 MODE=COPY
START_PRINT EXTRUDER=0 EXTRUDERS=2 EXTRUDER_TEMP=210 EXTRUDER1_TEMP=210 BED_TEMP=60
AREA_START=29.7633,79.7414 AREA_END=113.206,129.259
G21 ; set units to millimeters
G90 ; use absolute coordinates
M82 ; use absolute distances for extrusion
G92 E0

Bully85, 2024-02-15:
Hast du irgendwas an den cfg Dateien geändert?

ginwer7619, 2024-02-15:
Nein alles übernommen wie runtergeladen. Könnte höchstens Prusa löschen und neu installieren. Dort hatte ich verschiedene änderungen gemacht für meine umgebaute creality. Könnte das Problem davon kommen.

Bully85, 2024-02-15:
Hast du discord? Am besten schickst du mir mal den gcode und ich schau mal. Ich glaube nicht unbedingt dass deine Änderungen bei anderen Druckern hier zu trage kommen aber ausschließen kann ich es nicht wichtig ist zu wissen was im gcode steht.

Hast du auch die aktuellen cfg und prusa Profile aus meinem Release?

ginwer7619, 2024-02-15:
Discord habe ich nicht. cfg und Prusa profile sind as dem release.

Bully85, 2024-02-15:
Was hast du als gcode flavor in prusa

ginwer7619, 2024-02-15:
Habe soeben was im mirror mode versucht, dort klappt es. Werde Prusa neu installieren und morgen nochmal versuchen im copy mode.

Bully85, 2024-02-15:
Ok halt mich auf den Stand

ginwer7619, 2024-02-16:
Hallo, nach Neuinstallation von Prusa klappt es jetzt. Das einzige was ist, die Prime Line ist mir etwas zu weit im Bett. Wo kann ich den Abstand verringern. Ich hatte das normalerweise im G-Code auf 5mm stehen (G1 X5.0 Y20 Z0.3 F5000.0 ; Move to start position
G1 X5.0 Y200.0 Z0.3 F1500.0 E15 ; Draw the first line
G1 X5.4 Y200.0 Z0.3 F5000.0 ; Move to side a little
G1 X5.4 Y20 Z0.3 F1500.0 E30 ; Draw the second line)
ist aber jetzt auf etwa 15mm.
Im Start_End macro steht nur PRIME_LINE habe aber nicht heraus gefunden wo man die Angaben dazu machen kann.

ginwer7619, 2024-02-16:
Habs gefunden, Danke. Da hatte ich natürlich nicht gekuckt. Noch eine Frage zur Anzeige, dort ist die Anzeige der Ventilatoren nicht komplett, ist das auch irgendwo einstellbar.
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

Bully85, 2024-02-16:
Im Copy Mode und Miro Mode gibt es keine zwei

ginwer7619, 2024-02-16:
Was bedeutet dann das 2te F: 5. Der Ventilator vom rechten Druckkopf läuft aktuell mit 50% daher die Annahme dass da der Schluss fehlt in der Anzeige.

ginwer7619, 2024-02-16:
Ich habe auch unter Klipper sie Anzeige Unofficial remote url: https://github.com/Bully85/klipper Wie kann ich dies beheben. In Kiauh habe ich die Datei geändert wie Beschrieben.

Bully85, 2024-02-16:
Okay, schade dass du recht hast. Da wird was abgeschnitten sein muss ich heute Abend mal bei mir schauen wie es aussieht

Bully85, 2024-02-16:
Das kannst du beheben, indem du Softrepair machst

ginwer7619, 2024-02-16:
Hallo, noch ein Problem. Ich drucke aktuell nur mit dem rechten Druckkopf. Dabei zeigt der Bildschirm Layer und Filament komplett daneben an. Aktuell müsste er irgendwo um Layer 80 sein. Ist das auch irgendwo zu beheben?
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

Bully85, 2024-02-16:
Mit dem Recht im Kopf in Dual Modus oder Rechtsmodus

ginwer7619, 2024-02-22:
Hallo, gibt es ein Problem im copy mode mit Support's. Wenn ich im copy mode drucken möchte mit support drucken beide Köpfe vom ersten Layer den Support und dann geht der linke Kopf in Park Stellung und der rechte fährt auf die linke Druckseite (original) und fängt an zu drucken jedoch ohne Materialvorschub. Beide Düsen und Bett bleiben auf Drucktemperatur. Drucke ich das gleiche Teil zum Test ohne Support geht es. Slicer ist Prusa mit Ihren Einstellungen
Vielen Dank

ginwer7619, 2024-03-16:
> Okay, scheint dass du recht hast. Da wird was abgeschnitten sein muss ich heute Abend mal bei mir schauen wie es aussieht

Hallo, schon was raus gefunden mit den abgeschnittenen Anzeigen?

Bully85, 2024-03-16:
Bin im Moment mit meiner Arbeit sehr eingespannt. Sobald ich Luft finde, schaue ich nach allen Problemen, die bis jetzt auftreten.

ginwer7619, 2024-04-05:
Hallo, ich habe ein Problem nachdem input shapper gemacht wurde. Beim Drucken wird Home und Z-Tilt normal ausgeführt jedoch beim Bed Mesh (Komplet oder Area) kommt nach der 1ten Messstelle eine Fehlermeldung BLTouch failed to deploy danach Failed to verify BLTouch probe is raised; retrying. und nochmal BLTouch failed to deploy und der Drucker bleibt stehen. Nach der ersten Messung zieht Bltouch den Messstift zurück. Klammere ich in Printer.cfg die input-shaper Zeilen aus geht wieder alles normal. Muss da noch was irgendwo geändert werden dass BlTouch keinen Fehler erzeugt? Alle Dateien sind original. Vielen Dank.

ginwer7619, 2024-04-08:
Hallo, Bed Mesh Problem gelöst. Habe probe_with_touch_mode: True unter bltouch eingefügt und schon klappt's.
Mit freundlichen Grüßen.

ginwer7619, 2024-07-25:
> > Okay, scheint dass du recht hast. Da wird was abgeschnitten sein muss ich heute Abend mal bei mir schauen wie es aussieht
>
> Hallo, schon was raus gefunden mit den abgeschnittenen Anzeigen?

Hallo, Gibts schon was neues betreffend der abgeschnittenen Anzeige (meine Nachricht vom 16/02/24)?

Mit freundlichen Grüßen.

Bully85, 2024-07-25:
Hast du mittlerweile mal Klipperscreen geupdated?

ginwer7619, 2024-07-25:
Hallo,Ja alles auf dem letzten Stand. Le 25 juil. 2024 à 19:32, Bully85 ***@***.***> a écrit :
Hast du mittlerweile mal Klipperscreen geupdated?

—Reply to this email directly, view it on GitHub, or unsubscribe.You are receiving this because you authored the thread.Message ID: ***@***.***>

Closed 2024-10-15.

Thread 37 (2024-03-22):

Full guide from scratch?

petrovs12, 2024-03-22:
Hi,
I am thinking to buy one of these printers, and I get how to upload the config and flash the raspberry, but is there also a guide what needs to be done hardware-wise to the main board as well? The readme seems to assume the electronic mods are already done, where may I find a step by step guide for that part?

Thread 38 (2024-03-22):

Won't switch carriage in dual mode.

StrikerTC, 2024-03-22:
Every time I try to print in dual mode, when it's supposed to change from T0 to T1, T1 start extruding but T0 moves on the print path. Basically, the tool changes but the carriage does not. I can activate T0 or T1 macros and they move as they should. I'm not sure what I'm missing or if it's a slicer or klipper config issue. I'm using superslicer with your prusaslicer config/start gcode. Any ideas on whats going on?

[config-20240322-154040.zip](https://github.com/Bully85/Sovol-SV04-Klipper/files/14727992/config-20240322-154040.zip)

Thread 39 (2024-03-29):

Unable to parse move

aquari86, 2024-03-29:
It works so far, but when I want to print I get the error,
" Unable to parse move 'G1 Z{retraction_hop_height_after_extruder_switch} F12000' "

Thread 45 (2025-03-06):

Doesn't seem to apply XY offsets until first toolchange.

TraumatizedTuna, 2025-03-06:
When printing a part that starts off with only T1, I got a weird layer shift about the size of my offset as soon as T0 kicked in. I'll dig into it when I have time unless someone beats me to it.

StarLordMaks, 2025-05-09:
hello, i had same problem, for me worked adding T0 to the start g-code

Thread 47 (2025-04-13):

Z enable pins switched

Moosdijk, 2025-04-13:
The enable_pin for Z1 and Z2 are switched.

Z1 pin_enable = !PC5. Should be !PB5.
Z2 pin_enable = !PB5. Should be !PC5

Double check here:
https://github.com/Bjoern70/SV04-IDEX-3D-Printer-Mainboard-Source-code/blob/master/Marlin/src/pins/stm32f1/pins_CREALITY_V4.h
line 127 and 135

and:
https://github.com/jbu313mlb92ome8w/Sovol_SV04/blob/main/Photos/Pins_v3.png

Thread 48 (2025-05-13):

Error evaluating 'gcode_macro START_PRINT:gcode': jinja2.exceptions.UndefinedError: 'dict object' has no attribute 'EXTRUDER'

CO-Builder12, 2025-05-13:
This error is with all fresh bully85 macros (no others).

Moosdijk, 2025-05-25:
This repo has not been updated in almost 2 years and the discord has been dead for equally as long. I think you're better off creating a fork and updating it with your improvements.

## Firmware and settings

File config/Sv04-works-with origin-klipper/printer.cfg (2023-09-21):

## *** THINGS TO CHANGE/CHECK: ***
## MCU paths                            [mcu] section (printer.cfg)
## Thermistor types                     [extruder] and [heater_bed] sections - See 'sensor types' list at end of file (printer.cfg/IDEX_mode.cfg)
## PID tune                             [extruder] and [heater_bed] sections (printer.cfg/IDEX_mode.cfg)
## Fine tune E steps                    [extruder] section / rotation distance (printer.cfg/IDEX_mode.cfg)
## Select Z                             [z_stepper] section (printer.cfg)
## Z-Offset                             (Webhost/Display)
## X-Y Offset                           (Webhost MACRO X_Y OFFSET/IDEX_mode.cfg DC_VARS)
## Clean Nozzle                         [START_PRINT] (Start_End_Macro.cfg)
## Bed Mesh start Print
## Input shaper                         #[include adxl345.cfg] = deactivate [include adxl345.cfg] = deactivate (Webhost [gcode_macro ADXL_X],[gcode_macro ADXL_DC],[gcode_macro ADXL_Y])

################################################################################
# Included configs
################################################################################

[include macros.cfg]
#[include adxl345.cfg]
[include IDEX_mode.cfg]
[include misc.cfg]
[include Start_End_Macro.cfg]


[mcu]
baud: 115200
restart_method: command
serial: /dev/serial/by-id/usb-1a86_USB_Serial-if00-port0

#[temperature_sensor temperature_mcu]
#sensor_type: temperature_mcu
#sensor_mcu: mcu

#[temperature_sensor temperature_host]
#sensor_type: temperature_host
#sensor_path: /sys/class/thermal/thermal_zone0/temp

[force_move]
enable_force_move: True

[printer]
kinematics: cartesian
max_velocity: 300
max_accel: 1000
max_accel_to_decel: 500
square_corner_velocity: 8.0
max_z_velocity: 20
max_z_accel: 50


#####################################################################
#      X/Y Stepper Settings
#####################################################################

[stepper_x]
step_pin: PD15
dir_pin: !PD14
enable_pin: !PC7
microsteps: 16
rotation_distance: 50
endstop_pin: !PD10
position_min: -65
position_endstop: -62
position_max: 302
homing_speed: 80


[stepper_y]
step_pin: PB7
dir_pin: PB6
enable_pin: !PB9
rotation_distance: 40
microsteps: 16
endstop_pin: !PE0
position_endstop: 0
position_max: 302
homing_speed: 80

    

#####################################################################
#   Z Stepper Settings
#####################################################################

######## Use this if yor Chip is STM32 ##############

[stepper_z]
step_pin: PA7
dir_pin: !PA6
enable_pin: !PC5
microsteps: 16 
rotation_distance: 8
position_max: 400
position_min: -3
endstop_pin: probe:z_virtual_endstop
homing_speed: 10


[stepper_z1]
step_pin: PB3
dir_pin: !PD7
enable_pin: !PB5
microsteps: 16 
rotation_distance : 8

###### Use this if yor Chip is Giga Device GD32########

#[stepper_z]
#step_pin: PB3
#dir_pin: !PD7
#enable_pin: !PC5
#microsteps: 16 
#rotation_distance: 8
#position_max: 400
#position_min: -3
#endstop_pin: probe:z_virtual_endstop
#homing_speed: 10


#[stepper_z1]
#step_pin: PA7
#dir_pin: !PA6
#enable_pin: !PB5
#microsteps: 16 
#rotation_distance : 8


#####################################################################
#   Extruder
#####################################################################

[extruder]
step_pin: PD1
dir_pin: !PD0
enable_pin: !PD4
microsteps: 16
rotation_distance: 7.680
nozzle_diameter: 0.400
filament_diameter: 1.750
heater_pin: PA1
sensor_type: EPCOS 100K B57560G104F
sensor_pin: PA4
control: pid
pid_Kp:25.937
pid_Ki:1.465
pid_Kd:114.773
min_temp: 0
max_temp: 300
min_extrude_temp: 1
max_extrude_only_distance: 100
smooth_time: 0.2
full_steps_per_rotation: 200
#pressure_advance: 0.0
#pressure_advance_smooth_time: 0.020
#max_extrude_cross_section: 50


##########################################################
# Definition for the secondary carriage X2 and extruder 1
##########################################################

[dual_carriage]
axis: x
step_pin: PE9
dir_pin: !PE8
enable_pin: !PE11
microsteps: 16
rotation_distance: 50
endstop_pin: !PE15
position_endstop: 360
position_max: 360
homing_speed: 50


[extruder1]
step_pin: PB1
dir_pin: !PB0
enable_pin: !PE7
microsteps: 16
rotation_distance: 7.680
nozzle_diameter: 0.400
filament_diameter: 1.750
heater_pin: PA0
sensor_type: EPCOS 100K B57560G104F
sensor_pin: PA5
control: pid
pid_Kp:24.747
pid_Ki:1.363 
pid_Kd:112.287
min_temp: 0
max_temp: 300
min_extrude_temp: 1
max_extrude_only_distance: 100
smooth_time: 0.2
full_steps_per_rotation: 200
#pressure_advance: 0.0
#pressure_advance_smooth_time: 0.020
#max_extrude_cross_section: 4


#####################################################################
#   Bed Heater
#####################################################################

[heater_bed]
heater_pin: PA2
sensor_type: EPCOS 100K B57560G104F
sensor_pin: PA3
min_temp: 0
max_temp: 113
control: pid
pid_Kp: 312.84
pid_Ki: 52.04
pid_Kd: 1253.64


#####################################################################
#   Probe
#####################################################################

[bltouch]
sensor_pin: ^PD12
control_pin: PD13
x_offset: 0
y_offset: 25
z_offset: 0
speed: 10
stow_on_each_sample: False
samples: 2

[z_tilt]
z_positions: 10,150
            290,150
points: 50,150.5
        280,150.5
retries: 10
retry_tolerance: 0.02
speed:100

[bed_mesh]
speed: 200
horizontal_move_z: 5
mesh_min: 10,45
mesh_max: 290, 270
probe_count: 6,6

[bed_screws] # BED_SCREWS_ADJUST
screw1: 25,35
screw1_name: front left screw
screw4:	295,35
screw2_name: front right screw
screw3: 295,295
screw3_name: back right screw
screw2: 25,295
screw4_name: back left screw
speed: 150

[screws_tilt_adjust]
screw1: 31,0
screw1_name: Front Left
screw2: 270,0
screw2_name: Front Right
screw3: 270,240
screw3_name: Rear Right
screw4: 31,240
screw4_name: Rear Left
horizontal_move_z: 10.
speed: 100
screw_thread: CW-M4

#[safe_z_home]
#home_xy_position:150.5,150.5
#speed:150
#z_hop:10
#z_hop_speed:5

####################################
# Homing override for Z axis
# When homing command includes Home Z, it is critical to ensure correct
# extruder is selected to be centered on the bed before probing to
# prevent bed damage. Homing process is overridden to include T0 macro
# prior to homing process.  - Kevin Palmer
####################################

#################### Thanks to Kevin Palmer  #####################################

[homing_override]
axes: z
gcode:
 T0
 G90 ;absolute positioning
 G1 Z10 F600
 G28 X0
 G28 Y0

 G1 X150.5 Y150.5 F9000
 G28 Z0
 G1 Z10
set_position_z:0


#####################################################################
#   Runoutsensor
#####################################################################

[filament_switch_sensor Left]
pause_on_runout: False
runout_gcode: M600
switch_pin: PE5

[filament_switch_sensor Right]
pause_on_runout: False
runout_gcode: M600
switch_pin: PE6

## 	Thermistor Types
##   "EPCOS 100K B57560G104F"
##   "ATC Semitec 104GT-2"
##   "ATC Semitec 104NT-4-R025H42G"
##   "NTC 100K beta 3950"
##   "Honeywell 100K 135-104LAG-J01"
##   "NTC 100K MGB18-104F39050L32" (Keenovo Heater Pad)
##   "AD595"
##   "PT100 INA826"
##   "PT1000"

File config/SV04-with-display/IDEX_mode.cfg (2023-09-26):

# This file contains a configuration snippet for a dual extruder
# printer using dual carriages (an "IDEX" printer).

# See docs/Config_Reference.md for a description of parameters.

# Definition for the primary carriage (holding the primary extruder)
# and the definition for the primary extruder in main config file


# T0 print cooling fan
[fan_generic fanX1]
pin: PB14
cycle_time: 0.0100
kick_start_time: 1.00
hardware_pwm: false

# T1 print  cooling fan
[fan_generic fanX2]
pin: PB12
cycle_time: 0.0100
kick_start_time: 1.000
hardware_pwm: false

########################################
# DUAL-CARRIAGES
########################################

[respond]

[gcode_macro DC_VARS]
# Offset coordinates for dual_carriage
variable_offset_x: 0
variable_offset_y: 0
variable_offset_z: 0
# Autopark parameters
## default autopark: 0:inactive - 1:active
variable_autopark: 1
variable_z_hop: 2.0
variable_movespeed: 500
variable_feedrate: 30000
# HeatBed size
variable_bed_x_min: 0
variable_bed_x_max: 302
# Print cooling fans names
variable_fan0: 'fanX1'
variable_fan1: 'fanX2'
# Extruders temp
variable_offset_temp: 0
gcode:

## Set XY offset for dual mode

[gcode_macro XY_offset_dual]
description: Set XY offset for dual mode
gcode:
    {% set OFFSET_X = params.X_OFFSET | default(0) | float %}
    {% set OFFSET_Y = params.Y_OFFSET | default(0) | float %}
    
    SET_GCODE_VARIABLE MACRO=DC_VARS VARIABLE=offset_x VALUE={ OFFSET_X }
    SET_GCODE_VARIABLE MACRO=DC_VARS VARIABLE=offset_y VALUE={ OFFSET_Y }

    SAVE_VARIABLE VARIABLE=dual_x_offset VALUE={OFFSET_X}
    SAVE_VARIABLE VARIABLE=dual_y_offset VALUE={OFFSET_Y}

    M117 {OFFSET_X}
    M117 {OFFSET_Y}

## DUAL-CARRIAGES : FULL_CONTROL - AUTO-PARK

[gcode_macro T0]
description: Activate T0 
gcode:
    {% set dcvars = printer["gcode_macro DC_VARS"] %}
    {% if printer.dual_carriage is defined %}
        {% if printer.dual_carriage.carriage_1 == "PRIMARY" %}
            M400
            {% if dcvars.autopark == 1 %}
                # z-hop
                {% if dcvars.z_hop|float > 0.0 %}
                    {% set max_z = printer.toolhead.axis_maximum.z|float %}
                    {% set cur_z = printer.toolhead.position.z|float %}
                    {% set z_safe = dcvars.z_hop|float if cur_z < (max_z - dcvars.z_hop|float) else (max_z - cur_z) %}
                    G91
                    G1 Z{z_safe}
                    G90
                {% endif %}
                # park tool
                SAVE_GCODE_STATE NAME=toolhead_state
                _PARK_TOOL
            {% endif %}
            # toggle carriage
            ACTIVATE_EXTRUDER EXTRUDER=extruder
            SET_DUAL_CARRIAGE CARRIAGE=0
            {% if dcvars.autopark == 1 %}
                RESTORE_GCODE_STATE NAME=toolhead_state MOVE=1 MOVE_SPEED={dcvars.movespeed}
            {% endif %}
            # offsets
            SET_GCODE_OFFSET X=0 Y=0 Z=0
            # print fan speed
            _SET_PRINT_FANS_SPEED
            # restore z
            {% if (z_safe) is defined and printer.idle_timeout.state != "Printing" %}
                G91
                G1 Z-{z_safe}
                G90
            {% endif %}
        {% endif %}
    {% endif %}

[gcode_macro T1]
description: Activate T1 
gcode:
    {% set OFFSET_X = printer.save_variables.variables.dual_x_offset %}
    {% set OFFSET_Y = printer.save_variables.variables.dual_y_offset %}
    {% set dcvars = printer["gcode_macro DC_VARS"] %}
    {% if printer.dual_carriage is defined %}
        {% if printer.dual_carriage.carriage_0 == "PRIMARY" %}
            M400
            {% if dcvars.autopark == 1 %}
                # z-hop
                {% if dcvars.z_hop|float > 0.0 %}
                    {% set max_z = printer.toolhead.axis_maximum.z|float %}
                    {% set cur_z = printer.toolhead.position.z|float %}
                    {% set z_safe = dcvars.z_hop|float if cur_z < (max_z - dcvars.z_hop|float) else (max_z - cur_z) %}
                    G91
                    G1 Z{z_safe}
                    G90
                {% endif %}
                # park tool
                SAVE_GCODE_STATE NAME=toolhead_state
                _PARK_TOOL
            {% endif %}
            # toggle carriage
            ACTIVATE_EXTRUDER EXTRUDER=extruder1
            SET_DUAL_CARRIAGE CARRIAGE=1
            {% if dcvars.autopark == 1 %}
                RESTORE_GCODE_STATE NAME=toolhead_state MOVE=1 MOVE_SPEED={dcvars.movespeed}
            {% endif %}
            # offsets
            {% if dcvars.offset_x != 0 %}
                SET_GCODE_OFFSET X={dcvars.offset_x} Y={dcvars.offset_y} Z={dcvars.offset_z}
            {% else %}
                SET_GCODE_OFFSET X={OFFSET_X} Y={OFFSET_Y} Z={dcvars.offset_z}
            {% endif %}
            # print fan speed
            _SET_PRINT_FANS_SPEED
            # restore z
            {% if (z_safe) is defined and printer.idle_timeout.state != "Printing" %}
                G91
                G1 Z-{z_safe}
                G90
            {% endif %}
        {% endif %}
    {% endif %}

[gcode_macro _PARK_TOOL]
gcode:
    {% set dcvars = printer["gcode_macro DC_VARS"] %}
    {% if printer.dual_carriage is defined %}
        SAVE_GCODE_STATE NAME=park_tool
        SET_GCODE_OFFSET X=0 Y=0 Z=0
        G90
        {% if printer.toolhead.extruder == 'extruder' %}
            G1 X{printer.configfile.config.stepper_x.position_endstop} F{dcvars.feedrate}
        {% elif (printer.toolhead.extruder) == 'extruder1' %}
            G1 X{printer.configfile.config.dual_carriage.position_endstop} F{dcvars.feedrate}
        {% else %}
            RESPOND TYPE=error MSG={ "Unknown extruder: %s".format(printer.toolhead.extruder) }
        {% endif %}
        RESTORE_GCODE_STATE NAME=park_tool
    {% endif %}
    
## DUAL-CARRIAGES : MODES ACTIVATION

[gcode_macro M605]
description: Set the dual-carriages mode
gcode:
    {% set mode = params.S|default(1)|int %}
    {% set offset_temp = params.R|default(0)|float %}
    {% if printer.dual_carriage is defined %}
        {% if (mode) == 0 %}
            SET_GCODE_VARIABLE MACRO=DC_VARS VARIABLE=autopark VALUE=0
            MODE_FULL_CONTROL
        {% elif (mode) == 1 %}
            SET_GCODE_VARIABLE MACRO=DC_VARS VARIABLE=autopark VALUE=1
            MODE_FULL_CONTROL
        {% elif (mode) == 2 and (params.X) is defined %}
            ACTIVATE_COPY_MODE X={params.X} R={offset_temp}
        {% elif (mode) == 2 %}
            ACTIVATE_COPY_MODE R={offset_temp}
        {% elif (mode) == 3 %}
            ACTIVATE_MIRROR_MODE R={offset_temp}
        {% endif %}
        G1 F3000
    {% endif %}

[gcode_macro ACTIVATE_COPY_MODE]
description: Set the dual-carriages mode to "DUPLICATION"
gcode:
    {% set dcvars = printer["gcode_macro DC_VARS"] %}
    {% set bed_x_mid = 0.5 * (dcvars.bed_x_max|float - dcvars.bed_x_min|float) %}
    {% set offset_temp = params.R|default(0)|float %}
    {% if printer.dual_carriage is defined %}
       SET_DUAL_CARRIAGE CARRIAGE=0 MODE=PRIMARY
       G1 X{dcvars.bed_x_min|float} F{dcvars.feedrate}
       ACTIVATE_EXTRUDER EXTRUDER=extruder
       SET_DUAL_CARRIAGE CARRIAGE=1 MODE=PRIMARY
       G1 X{params.X|default(bed_x_mid)|float} F{dcvars.feedrate}
       SET_DUAL_CARRIAGE CARRIAGE=1 MODE=COPY
       SYNC_EXTRUDER_MOTION EXTRUDER=extruder1 MOTION_QUEUE=extruder
       M117 Copy Mode
    {% endif %}

[gcode_macro ACTIVATE_MIRROR_MODE]
description: Set the dual-carriages mode to "MIRRORED"
gcode:
    {% set dcvars = printer["gcode_macro DC_VARS"] %}
    {% set offset_temp = params.R|default(0)|float %}
    {% if printer.dual_carriage is defined %}
       SET_DUAL_CARRIAGE CARRIAGE=0 MODE=PRIMARY
       G1 X{dcvars.bed_x_min|float} F{dcvars.feedrate}
       ACTIVATE_EXTRUDER EXTRUDER=extruder
       SET_DUAL_CARRIAGE CARRIAGE=1 MODE=PRIMARY
       G1 X{dcvars.bed_x_max|float} F{dcvars.feedrate}
       SET_DUAL_CARRIAGE CARRIAGE=1 MODE=MIRROR
       SYNC_EXTRUDER_MOTION EXTRUDER=extruder1 MOTION_QUEUE=extruder
       M117 Mirror Mode
    {% endif %}
    
## DUAL-CARRIAGES : PRINT FANS MANAGEMENT

[gcode_macro M106]
description: Override "M106" to allow multiple extruders.
gcode:
    {% set dcvars = printer["gcode_macro DC_VARS"] %}
    {% set raw_speed = params.S|default(0)|float %}
    {% set fan_speed = (raw_speed / 255.0)|round(2) %}
    {% if (params.P) is defined %}
        {% set P_fan = dcvars.fan0 if (params.P)|int == 0 else dcvars.fan1 %}
        SET_FAN_SPEED FAN={P_fan} SPEED={fan_speed}
    {% elif printer.dual_carriage is defined %}
        _SET_PRINT_FANS_SPEED SPEED={fan_speed}
    {% endif %}
    
[gcode_macro M107]
description: Override "M107" to allow multiple extruders.
gcode:
    M106 S0
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

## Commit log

2023-03-07 Global Upload
    [IDEX-Cube-WK_V2.3mf, IDEX_mode.cfg, SV04.STL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]
2023-03-10 Update printer.cfg
    Heater bei Max temp 113
    [printer.cfg]
2023-03-11 Update README.md
    Currently Cura 5.3 is not supported! but we are working on it...
2023-03-11 change readme and printer.cfg, add variables.cfg
    [printer.cfg, variables.cfg]
2023-03-15 Update IDEX_mode.cfg
    Error Fixed "_SYNC_EXTRUDERS_TEMP"
    [IDEX_mode.cfg]
2023-04-17 change for Display
    [IDEX_mode.cfg, printer.cfg, t5uid1.cfg]
2023-04-17 M300 bug
    [macros.cfg]
2023-04-18 print status dgus twin Display
    [Start_End_Macro.cfg, adxl345.cfg, macros.cfg]
2023-04-20 Homing Override
    I mostly print off the right extruder, and was having failed print cancellations due to a slicer end g-code issue, when I finally got it to home it would home with the right extruder active and drive it into the bed. After destroying a couple beds I created a homing override which calls T0 macro prior to homing. Works well in my testing.
    [printer.cfg]
2023-04-20 Fix homing with T1
    [printer.cfg]
2023-04-20 new printer Firmware
2023-09-21 new config
    [IDEX_mode.cfg, Start_End_Macro.cfg, adxl345.cfg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]
2023-09-23 Fix Bug with copy and mirror
    [IDEX_mode.cfg]
2023-09-26 Fix Fan bug
    [IDEX_mode.cfg]
